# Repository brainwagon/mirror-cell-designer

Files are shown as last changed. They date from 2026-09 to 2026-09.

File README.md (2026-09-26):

# Mirror Cell Designer

A browser app that designs 3D-printable push-pull mirror cells for Newtonian telescopes. It exports **STEP** and **3MF**.

- **Live app:** https://mvandewettering.com/mirror-cell-designer/ (hosted on GitHub Pages).
- **App:** [`mirror-cell-designer.html`](mirror-cell-designer.html). It is a single self-contained file. Open it straight from disk (`file://`). There is no build step. The first load needs an internet connection, because the CAD kernel (~23 MB), three.js and fflate come from jsDelivr. After that the browser caches them.
- **Examples:** [`examples/`](examples). A 6" mirror in an 8" ID tube, and an 8" mirror in a 10" ID tube.
- **Tools (optional):** [`tools/build-examples.mjs`](tools/build-examples.mjs) regenerates the examples and runs a regression sweep. It extracts its geometry code from the HTML file, so the examples always match the app.

## Using the app

1. Pick the **mirror diameter**: 4.25", 6", 8" or 10". Each preset fills in a typical mirror thickness, tube ID and fan. All of these can be edited.
2. Enter the **mirror thickness** and the **tube inside diameter**. The in/mm toggle only changes how these inputs display. Internally everything is in mm.
3. Choose **retention**: RTV glue or clips.
4. Choose a **cooling fan**, or none. Fans too large for the mirror are greyed out.
5. Set your **printer bed** size. The default is 235 mm (e.g. an Anycubic Kobra S1); enter 220 for the brief's standard bed.
   Choose the **rear plate** style: *Ring* (default) or *3 spokes*, which prints smaller.
6. Check the tabs:
   - **3D preview:** the assembly with the mirror ghosted. There are toggles for hardware, the tube and a half-section, an explode slider, and a *Print layout* view. That view shows each part in its print orientation on a bed square, and the square turns red if the part doesn't fit.
   - **2D layout:** a dimensioned sheet with a rear view of the rear plate, a front view of the mirror plate, a section through a push-pull pair, and the clip. Hole letters (A–K) refer to the hole schedule.
   - **Checks:** every wall-thickness, thread-engagement, bolt-travel and clearance check, the CAD interference matrix, and the bed fit.
   - **Dimensions & BOM:** key dimensions, the hole schedule (sizes, depths, radii, angles, install direction) and the complete bill of materials (see below).
   - **Design decisions:** the choices listed below.
7. **Export:** a 3MF with all parts ready to print, a STEP of the assembly (parts in place, named and coloured), per-part 3MF/STEP in print orientation, the **bill of materials as CSV**, the drawing as SVG, and a Markdown report.

The design regenerates about 0.25 s after each change. Settings are kept in the URL hash, so a link reproduces a design. They are also kept in `localStorage`.

## How the cell works

```
 tube end (z=0)                                      toward the sky (+z)
   │ skirt │ rear plate │  gap  │ mirror plate │ pads │  mirror  │ clip
   ┃       ┃████████████┃       ┃██████████████┃  ▐▌  ┃▒▒▒▒▒▒▒▒▒▒┃
   ┃       ┃   push ▶───────────┫ (bears)      ┃  ▐▌  ┃          ┃
   ┃       ┃ pull ◀═════════════════(insert in pad column)       ┃
```

- The **rear tube plate** is a slip fit inside the tube: its diameter is the tube ID minus a 0.6 mm diametral clearance. A skirt runs rearward and sits flush with the tube end. Screws go through the tube wall into radial heat-set inserts in the skirt: 3 screws for tubes under 200 mm ID, 6 above. They are the same size as the push-pull bolts, so the push-pull and tube attachment share one insert size. Three vent windows keep the plate open for airflow.
- The **mirror plate** is a round core with three tapered arms. The arms carry the lateral posts. The mirror sits on three **pad columns** on a circle of **0.65 × mirror diameter**, which is close to the optimum for 3-point support.
- There are **three push-pull pairs** at 120°. Each **pull bolt** passes through a clearance hole in the rear plate and threads into a heat-set insert at the bottom of a pad column. Each **push bolt** threads through a heat-set insert in a boss on the rear plate and bears on the back of the mirror plate. A jam nut locks it. Both heads are reachable from behind the tube.
- **Bolts:** #10-24 for 4.25" and 6" mirrors, 1/4-20 for 8" and 10". Default travel at each pair is ±1 mm for 4.25", ±1.5 mm for 6", ±2 mm for 8" and ±2.5 mm for 10". This is sized so the worst case (one pair fully out, two fully in) tilts the mirror about 2.5°, several times what collimation needs. You can change it under *Advanced*. If you choose more travel, the pull-bolt clearance holes are enlarged automatically so the bolts don't bind as they tilt. The **plate gap is chosen to fit the bolts**: the pull bolt is the shortest standard length that fully engages its insert at maximum gap, and the gap is then set so it never bottoms out at minimum gap. The BOM lists every bolt length.
- **RTV:** each pad has a 2 mm-deep cup that sets the silicone thickness, and three lateral stops sit 0.75 mm from the mirror edge. **Clips:** the pads are flat. Three posts carry 3 mm clips that overlap the mirror face by 3 mm and sit 0.8 mm above it, so they never pinch the glass.
- **Fan (optional):** mounted on the back of the rear plate and blowing into the tube. Air goes through the plate's central opening and a matching hole in the mirror plate. It is held by thread-forming screws for plastics (#4 for 40 mm fans, #6 for larger ones) driven from the back into printed pilot holes, so there are no inserts or nuts to reach after assembly. The app assumes 4010, 6015, 8025, 9225 and 12025 frames.

## Strength

Plate thicknesses, lateral-post depth, arm ribs and RTV pad size are **sized from hand calculations**, not fixed. Each calculation appears as a row in the *Strength* table on the Checks tab and in `REPORT.md`, with its value, allowable, percentage used and formula.

| Load case | Checks |
|---|---|
| **Tube horizontal:** the whole mirror weight × 2 bears sideways on one post, at the mirror's mid-thickness | Post-root bending **across the layers** (posts print upright); arm bending at the post (T-section with an optional rib); RTV shear; pull-bolt bending across the plate gap |
| **Tube vertical:** locked preload plus each pair's share of the mirror-side weight × 2 | Pull- and push-insert pull-out; push-bolt tip and washer bearing; local plate bending where the pull and push bolts of a pair load the plate in opposite directions (mirror plate and rear plate); rear-plate spokes carrying the load out to the skirt; tube-screw bearing in the skirt |
| **Tube pointing down:** mirror weight × 2 on the clips or RTV | Clip bending and clip-screw insert pull-out, or RTV tension |

**What gets sized:**

| Part | Rule |
|---|---|
| Rear plate | max(rule of thumb, preload bending, spoke bending) |
| Mirror plate | max(rule of thumb, preload bending); thickened further only if an arm rib, capped 2 mm below the mirror, can't carry the lateral load |
| Lateral posts | deep enough for bending across the layers |
| RTV pads | large enough in area for the RTV to carry the load in shear |

The 8" example is typical: rear plate 8 mm (rule), mirror plate 7 mm (preload), a 6 × 4 mm arm rib, and 11 mm posts. At a 100 N lock preload, insert pull-out is about 24% of its allowable.

**Assumptions** are in the `STRENGTH` table at the top of the core in the HTML; edit them if you have better data.

| Assumption | Value |
|---|---|
| Glass density | 2.5 g/cm³ (plate glass; borosilicate is lighter, so this is conservative) |
| Handling factor on gravity loads | × 2 |
| Allowable along the layers | 10 MPa |
| Allowable across the layers | 5 MPa |
| Allowable bearing | 15 MPa |
| Allowable RTV shear/tension | 0.2 MPa |
| Section efficiency (walls, skins, 40% infill) | 0.8 |
| Heat-set insert pull-out, sustained | #4-40 150 N, #6-32 250 N, #8-32 300 N, #10-24 400 N, 1/4-20 500 N |
| Push-pull lock preload (Advanced setting) | 100 N per bolt ≈ 0.1–0.13 N·m, i.e. finger-snug; the BOM gives the torque for each bolt |

The plastic allowables are set at roughly 1/4–1/5 of typical short-term strengths for printed PETG and ASA, to cover creep, layer adhesion and print variability. The insert values are deliberately low; short-term tests of similar inserts usually fail well above them.

**Limits:** these are simple beam and plate formulas, not FEA. The pair-bending model (moment ≈ F·s/2 over a width ≈ s) is the crudest of them. They catch parts that are badly undersized, but they don't prove a safety margin. Stiffness is not checked, and neither is how far collimation drifts from creep; the low sustained allowables are the only guard against creep.

## Bill of materials

The BOM covers everything needed to build one cell. It appears on the *Dimensions & BOM* tab and in the report. It downloads as CSV from the **BOM .csv** button in the sidebar or the **Download CSV** button above the table. The rows are:

| Ref | Category | Contents |
|---|---|---|
| P1… | Printed part | Rear tube plate, mirror plate, clips. Each gives material, envelope, print settings and, once the solids are built, the bed footprint (flagged if oversize) and solid volume. |
| S1… | Screw | Pull and push bolts, tube screws, clip screws and fan screws, each with thread size and standard inch length. |
| N1… | Nut / washer | Push-bolt jam nuts (with across-flats size) and SAE washers under the pull-bolt heads. |
| I1… | Heat-set insert | Every insert, with length and the hole it expects. Identical inserts are merged; for example, #6-32 inserts used by both the clips and the fan become one line of 7. |
| F1 | Fan | Size, frame and hole spacing, when a fan is selected. |
| C1… | Consumable | Neutral-cure RTV (RTV mode only) and filament. |
| T1… | Tool | Hex keys and wrench sized for the specified hardware, the drill for the tube holes, and a soldering iron with insert tips. |

The CSV columns are `Ref, Category, Qty, Description, Size / spec, Length, Used in, Notes, Configuration`. The file is UTF-8 with a byte-order mark, so Excel and LibreOffice display Ø and inch marks correctly. The *Configuration* column repeats the design summary (mirror, tube, retention, fan, bolt size) on every row, so rows stay identifiable after you paste them into a larger parts list.

## Design decisions

These are the "decide and state" items from the brief. The app shows the same list on its *Design decisions* tab.

| Topic | Decision |
|---|---|
| **CAD kernel** | **replicad 1.1.0**: OpenCascade compiled to WebAssembly, loaded from jsDelivr. A true B-rep kernel is needed to write real STEP. JSCAD is mesh-only CSG and cannot export STEP. 3MF is written by a small built-in writer from the kernel's triangulation. Vertices are welded, so the meshes are watertight. The zip uses `fflate`. |
| **3MF print defaults** | **5 walls/perimeters, 40 % gyroid infill, 5 top and 5 bottom layers, 0.2 mm layers, supports off.** Five 0.4 mm walls make the ≥ 2 mm of material around every heat-set insert solid perimeter rather than infill. 40 % gyroid keeps the plates stiff. The values are written as per-object overrides that PrusaSlicer reads (`Metadata/Slic3r_PE_model.config`). OrcaSlicer/Bambu equivalents are also written (`Metadata/model_settings.config`), on a best-effort basis. The values are repeated in the model description so you can set them by hand in any slicer. Recommended material: **PETG or ASA**. PLA creeps under constant bolt load and softens in a hot car. |
| **Oversize parts** | Every part's footprint is measured at its best rotation about Z. If it exceeds the bed (default **235 × 235 mm**), a warning names the part, gives its size and states the bed size needed. **The part is still exported whole and full size. The app never splits or scales parts**, because a seam through a collimation plate costs stiffness and flatness. Your options are the 3-spoke rear plate, a larger bed, or cutting the part yourself with your slicer's *Cut* tool and dowel connectors. In practice, on a 235 mm bed: every part for 4.25", 6" and 8" mirrors fits, as long as an 8" mirror uses the 3-spoke rear plate in tubes over about 9.25" ID. For example, a 10" tube's ring plate is 253 mm but its 3-spoke plate is about 223 mm. An 8" mirror needs at least about 9.4" tube ID for post and tilt clearance, and the check reports the minimum. A 10" mirror's mirror plate is about 250 mm whatever the rear plate style, because its lateral posts must sit outside a 254 mm mirror. |
| **Rear plate style** | *Ring* (default): a full plate with a skirt around the tube wall, 3 or 6 tube screws and vent windows. *3 spokes* (option): a hub carrying the push-pull pairs and fan, with one 24 mm spoke per pair centred between its pull and push bolts, ending in a pad at the tube wall with one radial tube screw (3 in total, same size as the push-pull bolts). The spoke style is about 13% smaller across (the three tips at 120° fit a smaller square than a circle does) and uses about 40% less plastic. Three pads centre the plate in the tube and tolerate an out-of-round tube better than a ring. The spokes are covered by the same strength, wall and interference checks, with fillets where each spoke meets the hub (6 mm, in plane) and where it meets its tip pad (3 mm). |
| **Print orientation, no supports** | Rear plate: front face down, so the skirt and bosses grow upward. The radial tube-screw holes are **teardrops** pointing up. Mirror plate: rear face down, with pads and posts growing upward. Blind insert holes open onto the bed, and their small (< 8 mm) roofs bridge. Clips print flat. |
| **Fasteners** | Imperial only. Push-pull and tube screws share one size: #10-24 for 4.25"/6" mirrors, 1/4-20 for 8"/10". Clips use #6-32 inserts. The fan uses #4 or #6 thread-forming screws in printed pilot holes (no inserts). Inserts are tapered brass heat-set inserts for plastics. The dimensions are in the `FASTENERS` table at the top of the core in the HTML. Edit them there if your inserts differ. |
| **Fillets** | Inside corners are filleted to reduce stress concentration. **Rear plate:** 3 mm where the plate web meets the skirt, 1.5 mm at each push-boss root, 4 mm vent-window corners. **Mirror plate:** 2 mm where each pad column meets the plate, 3 mm along the inner face of each lateral post (the face in tension when the tube is horizontal; capped so it stays ≥ 2 mm below the mirror), 2 mm along both sides of each arm rib, and 8 mm in plane where each arm meets the core (tangent to the tapered arm edge and the core circle). All face up when printed or are vertical, so none need supports. The strength formulas assume these fillets remove the sharp-corner stress raisers; they add no factor for them. The fan is rotated automatically to the angle that best clears the push-pull hardware. |
| **Strength** | Thicknesses, lateral-post depth, arm ribs and RTV pad size are sized by hand calculations against sustained allowables for printed PETG/ASA (see *Strength*). Lock the push-pull pairs finger-snug: about 100 N per bolt, the torque listed in the BOM. |
| **Wall rules** | The generator aims for 3 mm around inserts, measured from the insert's **outside** diameter, not the hole. Every insert and through-hole must have **≥ 2 mm** to the nearest hole, cut-out or edge. Blind holes keep ≥ 2 mm of cap. Cut-outs keep ≥ 4 mm of web to bolt features. |

### Assumed hardware (edit `FASTENERS` in the HTML if yours differ)

| Size | Clearance hole | Insert hole | Insert OD | Insert length |
|---|---|---|---|---|
| #4-40 | 3.4 | 3.2 | 3.8 | 3.8 |
| #6-32 | 4.0 | 4.0 | 4.6 | 4.8 |
| #8-32 | 4.7 | 4.7 | 5.3 | 5.6 |
| #10-24 | 5.4 | 5.6 | 6.3 | 6.4 |
| 1/4-20 | 7.0 | 7.6 | 8.4 | 8.0 |

Clearance holes are a "normal fit" plus about 0.2 mm for printing. Insert sizes vary by brand, so check the hole diameter your inserts call for.

## Verification (definition of done)

- **All dimensions specified:** the 2D sheet, the hole schedule (diameter, depth, radius, angle, install face), the key-dimension table and the BOM (CSV) with bolt lengths are all generated from the same numbers as the solids. Each example has a `REPORT.md` with the full set.
- **Wall thickness:** analytic 2D checks cover every insert and through-hole against every other hole, cut-out, boss edge and plate edge. They also cover blind-hole caps, insert-fits-in-boss, skirt thickness, clip-hole walls and radial-insert edge distance. The 6" example has 41 checks and the 8" clip example has 49, and all pass.
- **No interference:** the app builds every body at its installed position: rear plate, mirror plate, clips, mirror, tube (with screw holes), fan, and every bolt, washer and jam nut. It then runs an OpenCascade boolean intersection on **every pair**. The mirror side (mirror plate, clips, mirror) is also moved into all **8 extreme collimation poses** (each pair at +travel or −travel) and intersected with the tube and the rear plate. The pose model pivots about the pull-bolt holes in the rear plate. The same 8 poses drive analytic checks: radial clearance to the tube (≥ 1 mm), axial gap to the rear plate and the fan-screw tips, pull-bolt tilt room in its clearance hole, and slide of the push-bolt contact point. Touching faces count as zero overlap. Heat-set inserts are left out on purpose, since they are meant to melt into their holes. Pull-bolt engagement and bottoming, push-bolt length and radial clearance to the tube at full tilt are checked analytically. A negative control (the mirror lowered 0.5 mm into the pads, a push bolt 1 mm too long) was confirmed to be caught.
- **Downloads:** the STEP and 3MF buttons produce files in the browser. This was tested in headless Chrome loading the page from `file://`. The exported STEP re-imports into OpenCascade with the exact expected volumes. OrcaSlicer's `--info` reports every 3MF object as manifold, with volumes matching the CAD.
- **Strength:** 13–14 hand-calculation checks per configuration, covering three load cases. All pass for every preset, because the sized dimensions are chosen to satisfy them.
- **Regression sweep:** `node tools/build-examples.mjs --sweep` builds every preset × retention × fan combination and runs all checks plus the CAD interference test. Every buildable combination passes. Fans too big for a given mirror are rejected with a clear message: for example, anything over 40 mm on a 4.25" mirror, or over 60 mm on a 6".

## Regenerating the examples

```sh
cd tools
npm install
node build-examples.mjs                   # rewrites ../examples/*
node build-examples.mjs --sweep           # regression over all presets
node build-examples.mjs --mirror 8 --tube 9.25 --retention rtv --fan 60 --out ../my-cell
```

Each example folder contains:

| File | What it is |
|---|---|
| `*.3mf` | All printed parts, oriented and placed for printing, with the print settings embedded |
| `*-assembly.step` | Printed parts in their assembled positions (z = 0 at the tube end, +Z toward the sky) |
| `*-<part>-print.step` | Each part alone, in print orientation |
| `*-drawing.svg` | The dimensioned 2D layout |
| `*-bom.csv` | Complete bill of materials: printed parts, hardware, inserts, fan, consumables, tools |
| `REPORT.md` | Key dimensions, hole schedule, BOM, every check, interference matrix and bed fit |

| Example | Configuration | Bed fit (235 mm) |
|---|---|---|
| `6in-mirror-8in-tube` | 6" × 25.4 mm mirror, 8.000" ID, RTV, 60 mm fan, ring rear plate | all parts fit |
| `8in-mirror-10in-tube` | 8" × 32 mm mirror, 10.000" ID, clips, 80 mm fan, ring rear plate | **rear plate 253.4 mm — oversize** (needs ≥ 254 mm bed; see policy) |
| `8in-mirror-10in-tube-spokes` | same, with the 3-spoke rear plate | all parts fit (rear plate about 223 mm) |

## Assembly notes

1. Press the heat-set inserts in with the part cold and fully cured:
   - **Rear plate:** push-bolt inserts from the rear face and tube-screw inserts radially from outside the skirt.
   - **Mirror plate:** pull-bolt inserts from the rear face, and clip inserts from the tops of the posts.
2. **Wear pads:** on the mirror plate's rear face, cement a small steel flat washer over each of the three Ø1 mm marks (hole schedule M) using epoxy or CA. Use #6 SAE for #10-24 push bolts and #10 SAE for 1/4-20. The push-bolt tips then bear on steel, not plastic.
3. Fit the three push bolts with their jam nuts into the rear plate, backed out so they protrude only a little.
4. Put the pull bolts, with washers, through the rear plate and thread them into the mirror plate until the plates sit at roughly the nominal gap shown in the report.
5. **RTV:** put a blob of neutral-cure silicone in each pad cup. Lower the mirror onto the pad rims, which set the 2 mm layer. Leave it face-up for 24 h. **Clips:** place the mirror on the pads and screw the clips on. They should not touch the glass.
6. Slide the cell into the tube so the skirt is flush with the tube end. Drill through the tube at the skirt inserts (the angles and distance from the tube end are in the hole schedule) and fit the tube screws (same size as the push-pull bolts; drill size is in the BOM).
7. **Collimate:** loosen the push bolts, adjust with the pull bolts, then run the push bolts down and lock the jam nuts.

## Limitations

- Insert dimensions are generic. Confirm them against the inserts you buy.
- The OrcaSlicer/Bambu per-object settings in the 3MF are best effort. OrcaSlicer loads the files and reports them manifold, but I did not confirm that it applies the embedded wall and infill values. PrusaSlicer's per-object format is the primary one. Cura ignores both, so set the values by hand there.
- The app runs the CAD kernel on the main thread, so the page pauses for about 1–3 s while solids rebuild.

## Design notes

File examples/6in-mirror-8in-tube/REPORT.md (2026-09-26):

# Mirror cell: 6" mirror in 203.2 mm (8") ID tube

Retention: **RTV** · Fan: **60 mm** · Push-pull: **3 × #10-24 pairs** · Bed: 235 mm

## Key dimensions (mm)
| Group | Dimension | Value |
|---|---|---|
| Rear plate | Style | full ring (plate + skirt) |
| Rear plate | Outside diameter (tube ID − fit) | 202.6 mm (7.976") |
| Rear plate | Skirt inside diameter | 187 mm (7.362") |
| Rear plate | Overall height (skirt + plate) | 18 mm (0.709") |
| Rear plate | Plate thickness (sized) | 6.5 mm = max(rule 6, preload 6.5, spokes 2.5) |
| Rear plate | Push boss Ø × height | 12.3 × 10.4 mm |
| Push-pull | Bolt size | #10-24 |
| Push-pull | Pair circle diameter | 99.1 mm (3.9") |
| Push-pull | Pull-to-push spacing (chord) | 14.5 mm (16.83°) |
| Push-pull | Nominal plate gap | 16.15 mm (±1.5 mm travel) |
| Push-pull | Max tilt at full travel (one pair out, two in) | 2.31° |
| Mirror plate | Inside fillets: pad roots / post inner faces / rib sides / arm roots (in plane) | 2 / 3 / — / 8 mm |
| Rear plate | Inside fillets: skirt joint / boss roots / window corners | 3 / 1.5 / 4 mm |
| Mirror plate | Core diameter | 121.5 mm (4.782") |
| Mirror plate | Span across posts | 169.9 mm (6.689") |
| Mirror plate | Base thickness (sized) | 6.5 mm — governed by push-pull preload (rule 5, preload 6.5) |
| Mirror plate | Arm rib (width × height) | none needed |
| Mirror plate | Lateral post depth (sized) | 8 mm (minimum 8) |
| Loads | Mirror mass (glass at 2.5 g/cm³) | 1.16 kg |
| Loads | Push-pull lock preload / torque | 100 N per bolt ≈ 0.1 N·m (finger-snug) |
| Mirror plate | Pad Ø × height above base | 12.4 × 8.9 mm |
| Mirror plate | Post top above mirror-plate rear face | 28.1 mm |
| Mirror | Diameter / thickness | 152.4 / 25.4 mm |
| Mirror | Mirror face above tube end | 74.9 mm (2.951") |
| Assembly | Overall cell height | 74.9 mm (2.951") |

## Hole schedule
| Part | Label | Qty | Feature | Size | Location | Install |
|---|---|---|---|---|---|---|
| Rear plate | A | 3 | #10-24 heat-set insert (push bolt) | Ø5.6 thru boss (10.4 tall) | R49.53 @ 106.8°, 226.8°, 346.8° | from rear face |
| Rear plate | B | 3 | #10-24 clearance (pull bolt) | Ø5.4 thru | R49.53 @ 90°, 210°, 330° |  |
| Rear plate | C | 6 | #10-24 heat-set insert (tube screw), radial teardrop | Ø5.6 thru skirt (7.8) | 30°, 90°, 150°, 210°, 270°, 330°; 5.75 from tube end | from outside of skirt |
| Rear plate | D | 4 | #6 thread-forming screw pilot (fan) | Ø2.8 thru | 50 × 50 square, rotated 22° | screw in from rear face |
| Rear plate | E | 1 | Fan opening | Ø57 thru | centre |  |
| Rear plate | F | 3 | Vent window (annular sector) | R45.4–R89.5, 77.5° wide | 120.4°–197.9°, 240.4°–317.9°, 0.4°–77.9° |  |
| Mirror plate | G | 3 | #10-24 heat-set insert (pull bolt), blind | Ø5.6 × 10.9 deep | R49.53 @ 90°, 210°, 330° | from rear face (bed side) |
| Mirror plate | H | 3 | RTV cup in pad top | Ø9.4 × 2 deep | R49.53 @ 90°, 210°, 330° |  |
| Mirror plate | M | 3 | Wear-washer locating mark (push-bolt contact) | Ø1 × 1 deep | R49.53 @ 106.8°, 226.8°, 346.8° | rear face (bed side) |
| Mirror plate | I | 1 | Central vent | Ø57 thru | centre |  |
| Mirror plate | J | 3 | Vent hole | Ø24 thru | R44.61 @ 158.4°, 278.4°, 38.4° |  |

## Bill of materials (per cell)
| Ref | Category | Qty | Description | Size / spec | Length | Used in | Notes |
|---|---|---|---|---|---|---|---|
| P1 | Printed part | 1 | Rear tube plate | PETG or ASA; Ø202.6 × 18 mm |  | tube end | 5 walls, 40% gyroid, 0.2 mm layers, no supports; footprint 202.5 × 202.5 mm; solid volume 169.6 cm³ |
| P2 | Printed part | 1 | Mirror plate | PETG or ASA; 169.9 mm across posts × 28.1 mm tall |  | carries the mirror | 5 walls, 40% gyroid, 0.2 mm layers, no supports; footprint 148.9 × 148.9 mm; solid volume 67.1 cm³ |
| S1 | Screw | 3 | Socket head cap screw (pull / adjust) | #10-24 | 1-1/4" | rear plate → mirror plate pad inserts | a thumbscrew or knob of the same length also works; lock at ≈ 0.1 N·m |
| S2 | Screw | 3 | Socket head cap screw (push / lock) | #10-24 | 1-1/2" | rear-plate push bosses | fully threaded; lock at ≈ 0.1 N·m |
| S3 | Screw | 6 | Button head socket cap screw (tube attachment) | #10-24 | 1/2" | through tube wall into skirt | sized for a 3.18 mm tube wall |
| S4 | Screw | 4 | Thread-forming screw for plastics, pan head (fan mount) | #6 | 7/8" | fan → rear plate pilot holes | e.g. Hi-Lo or 48° plastic-forming thread; Ø2.8 mm pilot holes; don't overtighten |
| N1 | Nut / washer | 3 | Hex jam nut | #10-24 |  | push bolts | 3/8" across flats |
| N2 | Nut / washer | 3 | Flat washer, SAE | #10-24 |  | under pull-bolt heads | Ø12.7 mm OD |
| N3 | Nut / washer | 3 | Steel flat washer (wear pad for the push-bolt tip) | #6 SAE (≈ Ø9.5 OD, Ø4 hole, 1.2 thick) |  | cemented to the mirror plate rear face at the Ø1 marks | hole must be smaller than the Ø4.8 bolt tip; epoxy or CA |
| I1 | Heat-set insert | 12 | Brass heat-set insert (tapered, for plastics) | #10-24, 6.4 mm long, for Ø5.6 mm hole |  | rear plate, push bosses; mirror plate, pad columns; rear-plate skirt (radial) | install from rear face; install from outside |
| F1 | Fan | 1 | 60 mm 12 V DC fan | 6015 (60 × 60 × 15 mm), 50 mm hole spacing |  | rear face of rear plate | blows into the tube; 12 V supply and lead not included |
| C1 | Consumable | 1 | Neutral-cure silicone RTV | alkoxy/oxime cure — not acetic (vinegar-smelling) |  | pad cups | 3 blobs, 2 mm thick |
| C2 | Consumable | 1 | Filament | PETG or ASA |  | all printed parts | PLA not recommended (creeps under bolt load) |
| T1 | Tool | 1 | Hex key | 5/32" |  | #10-24 socket heads |  |
| T2 | Tool | 1 | Hex key | 1/8" |  | #10-24 button heads |  |
| T3 | Tool | 1 | Wrench | 3/8" |  | push-bolt jam nuts |  |
| T4 | Tool | 1 | Screwdriver | Phillips #2 |  | #6 fan screws |  |
| T5 | Tool | 1 | Drill bit | 13/64" (5.2 mm) |  | 6 tube-wall holes for #10-24 | positions are in the hole schedule (C) |
| T6 | Tool | 1 | Soldering iron with heat-set insert tips | #10-24 |  | installing inserts | or a dedicated insert press |

## Checks
| Part | Check | Value (mm) | Required | Result |
|---|---|---|---|---|
| Rear plate | wall around pull clearance hole P1 | 7.63 | ≥ 2 | PASS |
| Rear plate | wall around push insert P1 | 3 | ≥ 2 | PASS |
| Rear plate | wall around pull clearance hole P2 | 7.63 | ≥ 2 | PASS |
| Rear plate | wall around push insert P2 | 3 | ≥ 2 | PASS |
| Rear plate | wall around pull clearance hole P3 | 7.63 | ≥ 2 | PASS |
| Rear plate | wall around push insert P3 | 3 | ≥ 2 | PASS |
| Rear plate | wall around fan screw pilot F1 | 5.1 | ≥ 2 | PASS |
| Rear plate | wall around fan screw pilot F2 | 5.1 | ≥ 2 | PASS |
| Rear plate | wall around fan screw pilot F3 | 5.1 | ≥ 2 | PASS |
| Rear plate | wall around fan screw pilot F4 | 5.1 | ≥ 2 | PASS |
| Rear plate | solid bearing under pull washer P1 | 3.98 | ≥ 0.5 | PASS |
| Rear plate | push boss P1 (incl. root fillet) clear of cut-outs | 3.98 | ≥ 0.5 | PASS |
| Rear plate | solid bearing under pull washer P2 | 3.98 | ≥ 0.5 | PASS |
| Rear plate | push boss P2 (incl. root fillet) clear of cut-outs | 3.98 | ≥ 0.5 | PASS |
| Rear plate | solid bearing under pull washer P3 | 3.98 | ≥ 0.5 | PASS |
| Rear plate | push boss P3 (incl. root fillet) clear of cut-outs | 3.98 | ≥ 0.5 | PASS |
| Rear plate | wall: tube-screw insert to skirt edge | 2.6 | ≥ 2 | PASS |
| Rear plate | skirt thickness ≥ tube insert length | 1.4 | ≥ 0 | PASS |
| Rear plate | push insert fits boss height | 4 | ≥ 0 | PASS |
| Rear plate | wall between tube-screw inserts | 95 | ≥ 2 | PASS |
| Mirror plate | wall around pull insert P1 | 3.05 | ≥ 2 | PASS |
| Mirror plate | wall around pull insert P2 | 3.05 | ≥ 2 | PASS |
| Mirror plate | wall around pull insert P3 | 3.05 | ≥ 2 | PASS |
| Mirror plate | wear-washer seat P1 on solid plastic (Ø9.5, incl. 0.8 mm slide at full tilt) | 5.67 | ≥ 0.5 | PASS |
| Mirror plate | push-bolt tip (Ø4.83) larger than the wear-washer hole (Ø4) | 0.83 | ≥ 0.3 | PASS |
| Mirror plate | pad column P1 (incl. root fillet) clear of vents | 12.83 | ≥ 1 | PASS |
| Mirror plate | wear-washer seat P2 on solid plastic (Ø9.5, incl. 0.8 mm slide at full tilt) | 5.67 | ≥ 0.5 | PASS |
| Mirror plate | pad column P2 (incl. root fillet) clear of vents | 12.83 | ≥ 1 | PASS |
| Mirror plate | wear-washer seat P3 on solid plastic (Ø9.5, incl. 0.8 mm slide at full tilt) | 5.67 | ≥ 0.5 | PASS |
| Mirror plate | pad column P3 (incl. root fillet) clear of vents | 12.83 | ≥ 1 | PASS |
| Mirror plate | arm-root fillet (R8) ends inboard of the lateral post | 10.79 | ≥ 0 | PASS |
| Mirror plate | cap above pull insert hole | 2.5 | ≥ 2 | PASS |
| Push-pull | pull-bolt engagement at max gap (17.7 mm) | 6.4 | ≥ 6.4 | PASS |
| Push-pull | pull-bolt tip depth at min gap (14.7 mm) | 9.4 | ≤ 10.4 | PASS |
| Push-pull | push-bolt length left for jam nut at max gap | 10.05 | ≥ 4.2 | PASS |
| Push-pull | min plate gap at full travel | 14.65 | ≥ 5 | PASS |
| Push-pull | pair spacing (pull washer to push-boss root fillet) | 0.5 | ≥ 0.5 | PASS |
| Fan | fan-screw tip protrusion past plate front (must clear mirror plate) | 0.72 | ≤ 13.65 | PASS |
| Fan | fan-screw thread engagement in the plate (#6 thread-forming) | 6.5 | ≥ 5.27 | PASS |
| Assembly | radial clearance to tube, worst of 8 poses at ±1.5 mm per pair (2.3° max tilt, pose −++); needs tube ID ≥ 177.2 mm (6.98") | 14.01 | ≥ 1 | PASS |
| Assembly | axial gap mirror plate ↔ rear plate, worst pose (+−−) | 12.8 | ≥ 1 | PASS |
| Assembly | gap mirror plate ↔ fan-screw tips, worst pose | 13.51 | ≥ 0.5 | PASS |
| Push-pull | pull-bolt tilt room in rear-plate hole at 2.3° | 0.31 | ≥ 0.1 | PASS |
| Assembly | mirror edge to lateral post gap | 0.75 | ≥ 0.25 | PASS |
| Assembly | rear plate radial fit clearance | 0.3 | ≥ 0.1 | PASS |

## Strength (hand calculations, sustained allowables for printed PETG/ASA)
| Load case | Item | Value | Allowable | Utilisation | Result |
|---|---|---|---|---|---|
| Tube horizontal: 22.7 N lateral (mirror 1.16 kg × 2) | lateral post root bending, across layers (8 × 14 mm post, load 21.6 mm up) | 4.11 MPa | 5 MPa | 82% | PASS |
| Tube horizontal: 22.7 N lateral (mirror 1.16 kg × 2) | arm bending at the post (15.2 × 6.5 mm arm) | 6.6 MPa | 10 MPa | 66% | PASS |
| Tube horizontal: 22.7 N lateral (mirror 1.16 kg × 2) | RTV shear, 3 pads Ø9.4 mm | 0.11 MPa | 0.2 MPa | 55% | PASS |
| Tube horizontal: 22.7 N lateral (mirror 1.16 kg × 2) | pull-bolt bending across the gap (steel, #10-24 root Ø3.5) | 34.91 MPa | 250 MPa | 14% | PASS |
| Tube vertical: preload 100 N + 8.4 N weight share per pair | pull-bolt insert pull-out (mirror plate, #10-24) | 108.36 N | 400 N | 27% | PASS |
| Tube vertical: preload 100 N + 8.4 N weight share per pair | push-bolt insert pull-out (rear plate, #10-24) | 108.36 N | 400 N | 27% | PASS |
| Tube vertical: preload 100 N + 8.4 N weight share per pair | push-bolt load on mirror plate through the Ø9.5 wear washer | 1.86 MPa | 15 MPa | 12% | PASS |
| Tube vertical: preload 100 N + 8.4 N weight share per pair | pull-bolt washer bearing on rear plate | 1.04 MPa | 15 MPa | 7% | PASS |
| Tube vertical: preload 100 N + 8.4 N weight share per pair | mirror plate local bending at each pair (t = 6.5 mm) | 9.62 MPa | 10 MPa | 96% | PASS |
| Tube vertical: preload 100 N + 8.4 N weight share per pair | rear plate local bending at each pair (t = 6.5 mm) | 9.62 MPa | 10 MPa | 96% | PASS |
| Tube vertical: preload 100 N + 8.4 N weight share per pair | rear plate spokes carrying the mirror side to the skirt (66 mm wide) | 0.98 MPa | 10 MPa | 10% | PASS |
| Tube vertical: preload 100 N + 8.4 N weight share per pair | tube-screw bearing in the skirt (6 × #10-24, cell 1.82 kg) | 0.16 MPa | 15 MPa | 1% | PASS |
| Tube pointing down: 7.6 N on each RTV pad | RTV tension | 0.11 MPa | 0.2 MPa | 55% | PASS |

## Interference (CAD boolean intersection of every pair of bodies)
| Body A | Body B | Overlap volume (mm³) | Result |
|---|---|---|---|
| Rear tube plate | Mirror plate | 0 | PASS |
| Rear tube plate | Mirror | 0 | PASS |
| Rear tube plate | Tube | 0 | PASS |
| Rear tube plate | Fan | 0 | PASS |
| Rear tube plate | Bolts, nuts & washers | 0 | PASS |
| Mirror plate | Mirror | 0 | PASS |
| Mirror plate | Tube | 0 | PASS |
| Mirror plate | Fan | 0 | PASS |
| Mirror plate | Bolts, nuts & washers | 0 | PASS |
| Mirror | Tube | 0 | PASS |
| Mirror | Fan | 0 | PASS |
| Mirror | Bolts, nuts & washers | 0 | PASS |
| Tube | Fan | 0 | PASS |
| Tube | Bolts, nuts & washers | 0 | PASS |
| Fan | Bolts, nuts & washers | 0 | PASS |
| Mirror side tilted (worst of 8 poses, 2.3° max) | Tube | 0 | PASS |
| Mirror side tilted (worst of 8 poses, 2.3° max) | Rear tube plate | 0 | PASS |

## Print bed fit (235 × 235 mm)
| Part | Footprint (mm) | Height (mm) | Fits |
|---|---|---|---|
| Rear tube plate | 202.5 × 202.5 | 18 | yes |
| Mirror plate | 148.9 × 148.9 | 28.1 | yes |

## Print settings (embedded in the 3MF)
5 walls/perimeters, 40% gyroid infill, 5 top and 5 bottom layers, 0.2 mm layers, no supports. Material: PETG or ASA (avoid PLA: it creeps under the constant bolt load and softens in a hot car).

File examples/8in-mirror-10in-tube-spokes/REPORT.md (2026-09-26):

# Mirror cell: 8" mirror in 254 mm (10") ID tube

Retention: **clips** · Fan: **80 mm** · Push-pull: **3 × 1/4-20 pairs** · Bed: 235 mm

## Key dimensions (mm)
| Group | Dimension | Value |
|---|---|---|
| Rear plate | Style | 3 spokes (hub + spokes, 3 tube screws) |
| Rear plate | Spoke-tip circle diameter (tube ID − fit) | 253.4 mm (9.976") |
| Rear plate | Hub diameter | 158 mm (6.22") |
| Rear plate | Spoke / tip-pad width | 24 mm, spokes at 97.6°, 217.6°, 337.6° |
| Rear plate | Overall height (skirt + plate) | 21.5 mm (0.846") |
| Rear plate | Plate thickness (sized) | 8 mm = max(rule 8, preload 7, spokes 6.5) |
| Rear plate | Push boss Ø × height | 14.4 × 12 mm |
| Push-pull | Bolt size | 1/4-20 |
| Push-pull | Pair circle diameter | 132.1 mm (5.2") |
| Push-pull | Pull-to-push spacing (chord) | 17.5 mm (15.23°) |
| Push-pull | Nominal plate gap | 12.05 mm (±2 mm travel) |
| Push-pull | Max tilt at full travel (one pair out, two in) | 2.31° |
| Mirror plate | Inside fillets: pad roots / post inner faces / rib sides / arm roots (in plane) | 2 / 3 / 2 / 8 mm |
| Rear plate | Inside fillets: tip-pad joint / boss roots / spoke roots (in plane) | 3 / 1.5 / 6 mm |
| Mirror plate | Core diameter | 156.5 mm (6.161") |
| Mirror plate | Span across posts | 226.7 mm (8.925") |
| Mirror plate | Base thickness (sized) | 7 mm — governed by push-pull preload (rule 6, preload 7) |
| Mirror plate | Arm rib (width × height) | 6 × 4 mm |
| Mirror plate | Lateral post depth (sized) | 11 mm (minimum 11) |
| Loads | Mirror mass (glass at 2.5 g/cm³) | 2.59 kg |
| Loads | Push-pull lock preload / torque | 100 N per bolt ≈ 0.13 N·m (finger-snug) |
| Mirror plate | Pad Ø × height above base | 14.4 × 9 mm |
| Mirror plate | Post top above mirror-plate rear face | 48.8 mm |
| Mirror | Diameter / thickness | 203.2 / 32 mm |
| Mirror | Mirror face above tube end | 81.6 mm (3.211") |
| Assembly | Overall cell height | 85.4 mm (3.36") |

## Hole schedule
| Part | Label | Qty | Feature | Size | Location | Install |
|---|---|---|---|---|---|---|
| Rear plate | A | 3 | 1/4-20 heat-set insert (push bolt) | Ø7.6 thru boss (12 tall) | R66.04 @ 105.2°, 225.2°, 345.2° | from rear face |
| Rear plate | B | 3 | 1/4-20 clearance (pull bolt) | Ø7 thru | R66.04 @ 90°, 210°, 330° |  |
| Rear plate | C | 3 | 1/4-20 heat-set insert (tube screw), radial teardrop | Ø7.6 thru tip pad (9.4) | 97.6°, 217.6°, 337.6°; 6.75 from tube end | from outside of skirt |
| Rear plate | D | 4 | #6 thread-forming screw pilot (fan) | Ø2.8 thru | 71.5 × 71.5 square, rotated 22° | screw in from rear face |
| Rear plate | E | 1 | Fan opening | Ø76 thru | centre |  |
| Mirror plate | G | 3 | 1/4-20 heat-set insert (pull bolt), blind | Ø7.6 × 13.5 deep | R66.04 @ 90°, 210°, 330° | from rear face (bed side) |
| Mirror plate | H | 3 | #6-32 heat-set insert (clip), blind | Ø4 × 7.3 deep | R107.85 @ 90°, 210°, 330° | from top of post |
| Mirror plate | M | 3 | Wear-washer locating mark (push-bolt contact) | Ø1 × 1 deep | R66.04 @ 105.2°, 225.2°, 345.2° | rear face (bed side) |
| Mirror plate | I | 1 | Central vent | Ø76 thru | centre |  |
| Mirror plate | J | 3 | Vent hole | Ø32 thru | R58.12 @ 157.6°, 277.6°, 37.6° |  |
| Clip | K | 3 | #6-32 clearance | Ø4 thru | 9.25 from inner end |  |

## Bill of materials (per cell)
| Ref | Category | Qty | Description | Size / spec | Length | Used in | Notes |
|---|---|---|---|---|---|---|---|
| P1 | Printed part | 1 | Rear tube plate | PETG or ASA; Ø253.4 × 21.5 mm |  | tube end | 5 walls, 40% gyroid, 0.2 mm layers, no supports; footprint 223 × 222.2 mm; solid volume 155.4 cm³ |
| P2 | Printed part | 1 | Mirror plate | PETG or ASA; 226.7 mm across posts × 48.8 mm tall |  | carries the mirror | 5 walls, 40% gyroid, 0.2 mm layers, no supports; footprint 197.4 × 197.4 mm; solid volume 127.7 cm³ |
| P3 | Printed part | 3 | Mirror clip | PETG or ASA; 14.8 × 16 × 3 mm |  | clip posts | 5 walls, 40% gyroid, 0.2 mm layers, no supports; footprint 14.8 × 16 mm; solid volume 0.7 cm³ |
| S1 | Screw | 3 | Socket head cap screw (pull / adjust) | 1/4-20 | 1-1/4" | rear plate → mirror plate pad inserts | a thumbscrew or knob of the same length also works; lock at ≈ 0.13 N·m |
| S2 | Screw | 3 | Socket head cap screw (push / lock) | 1/4-20 | 1-1/4" | rear-plate push bosses | fully threaded; lock at ≈ 0.13 N·m |
| S3 | Screw | 3 | Button head socket cap screw (tube attachment) | 1/4-20 | 1/2" | through tube wall into skirt | sized for a 3.18 mm tube wall |
| S4 | Screw | 3 | Socket head cap screw (clips) | #6-32 | 3/8" | clips → clip posts |  |
| S5 | Screw | 4 | Thread-forming screw for plastics, pan head (fan mount) | #6 | 1-1/2" | fan → rear plate pilot holes | e.g. Hi-Lo or 48° plastic-forming thread; Ø2.8 mm pilot holes; don't overtighten |
| N1 | Nut / washer | 3 | Hex jam nut | 1/4-20 |  | push bolts | 7/16" across flats |
| N2 | Nut / washer | 3 | Flat washer, SAE | 1/4-20 |  | under pull-bolt heads | Ø15.9 mm OD |
| N3 | Nut / washer | 3 | Steel flat washer (wear pad for the push-bolt tip) | #10 SAE (≈ Ø12.7 OD, Ø5.6 hole, 1.2 thick) |  | cemented to the mirror plate rear face at the Ø1 marks | hole must be smaller than the Ø6.4 bolt tip; epoxy or CA |
| I1 | Heat-set insert | 9 | Brass heat-set insert (tapered, for plastics) | 1/4-20, 8 mm long, for Ø7.6 mm hole |  | rear plate, push bosses; mirror plate, pad columns; rear-plate spoke tips (radial) | install from rear face; install from outside |
| I2 | Heat-set insert | 3 | Brass heat-set insert (tapered, for plastics) | #6-32, 4.8 mm long, for Ø4 mm hole |  | clip posts | install from top of post |
| F1 | Fan | 1 | 80 mm 12 V DC fan | 8025 (80 × 80 × 25 mm), 71.5 mm hole spacing |  | rear face of rear plate | blows into the tube; 12 V supply and lead not included |
| C1 | Consumable | 1 | Filament | PETG or ASA |  | all printed parts | PLA not recommended (creeps under bolt load) |
| T1 | Tool | 1 | Hex key | 3/16" |  | 1/4-20 socket heads |  |
| T2 | Tool | 1 | Hex key | 5/32" |  | 1/4-20 button heads |  |
| T3 | Tool | 1 | Hex key | 7/64" |  | #6-32 clip screws |  |
| T4 | Tool | 1 | Wrench | 7/16" |  | push-bolt jam nuts |  |
| T5 | Tool | 1 | Screwdriver | Phillips #2 |  | #6 fan screws |  |
| T6 | Tool | 1 | Drill bit | 17/64" (6.7 mm) |  | 3 tube-wall holes for 1/4-20 | positions are in the hole schedule (C) |
| T7 | Tool | 1 | Soldering iron with heat-set insert tips | 1/4-20, #6-32 |  | installing inserts | or a dedicated insert press |

## Checks
| Part | Check | Value (mm) | Required | Result |
|---|---|---|---|---|
| Rear plate | wall around pull clearance hole P1 | 9.46 | ≥ 2 | PASS |
| Rear plate | wall around push insert P1 | 3 | ≥ 2 | PASS |
| Rear plate | wall around pull clearance hole P2 | 9.46 | ≥ 2 | PASS |
| Rear plate | wall around push insert P2 | 3 | ≥ 2 | PASS |
| Rear plate | wall around pull clearance hole P3 | 9.46 | ≥ 2 | PASS |
| Rear plate | wall around push insert P3 | 3 | ≥ 2 | PASS |
| Rear plate | wall around fan screw pilot F1 | 10.8 | ≥ 2 | PASS |
| Rear plate | wall around fan screw pilot F2 | 10.8 | ≥ 2 | PASS |
| Rear plate | wall around fan screw pilot F3 | 10.8 | ≥ 2 | PASS |
| Rear plate | wall around fan screw pilot F4 | 10.8 | ≥ 2 | PASS |
| Rear plate | solid bearing under pull washer P1 | 5.01 | ≥ 0.5 | PASS |
| Rear plate | push boss P1 (incl. root fillet) clear of cut-outs | 4.26 | ≥ 0.5 | PASS |
| Rear plate | solid bearing under pull washer P2 | 5.01 | ≥ 0.5 | PASS |
| Rear plate | push boss P2 (incl. root fillet) clear of cut-outs | 4.26 | ≥ 0.5 | PASS |
| Rear plate | solid bearing under pull washer P3 | 5.01 | ≥ 0.5 | PASS |
| Rear plate | push boss P3 (incl. root fillet) clear of cut-outs | 4.26 | ≥ 0.5 | PASS |
| Rear plate | wall: tube-screw insert to tip pad edge | 2.55 | ≥ 2 | PASS |
| Rear plate | wall: tube-screw insert to sides of spoke tip pad | 7.8 | ≥ 2 | PASS |
| Rear plate | skirt thickness ≥ tube insert length | 1.4 | ≥ 0 | PASS |
| Rear plate | push insert fits boss height | 4 | ≥ 0 | PASS |
| Rear plate | wall between tube-screw inserts | 211.05 | ≥ 2 | PASS |
| Mirror plate | wall around pull insert P1 | 3 | ≥ 2 | PASS |
| Mirror plate | wall around pull insert P2 | 3 | ≥ 2 | PASS |
| Mirror plate | wall around pull insert P3 | 3 | ≥ 2 | PASS |
| Mirror plate | wear-washer seat P1 on solid plastic (Ø12.7, incl. 0.6 mm slide at full tilt) | 5.2 | ≥ 0.5 | PASS |
| Mirror plate | push-bolt tip (Ø6.35) larger than the wear-washer hole (Ø5.6) | 0.75 | ≥ 0.3 | PASS |
| Mirror plate | pad column P1 (incl. root fillet) clear of vents | 18.84 | ≥ 1 | PASS |
| Mirror plate | wear-washer seat P2 on solid plastic (Ø12.7, incl. 0.6 mm slide at full tilt) | 5.2 | ≥ 0.5 | PASS |
| Mirror plate | pad column P2 (incl. root fillet) clear of vents | 18.84 | ≥ 1 | PASS |
| Mirror plate | wear-washer seat P3 on solid plastic (Ø12.7, incl. 0.6 mm slide at full tilt) | 5.2 | ≥ 0.5 | PASS |
| Mirror plate | pad column P3 (incl. root fillet) clear of vents | 18.84 | ≥ 1 | PASS |
| Mirror plate | arm-root fillet (R8) ends inboard of the lateral post | 19.08 | ≥ 0 | PASS |
| Mirror plate | cap above pull insert hole | 2.5 | ≥ 2 | PASS |
| Mirror plate | wall around clip insert C1 | 3.2 | ≥ 2 | PASS |
| Mirror plate | wall around clip insert C2 | 3.2 | ≥ 2 | PASS |
| Mirror plate | wall around clip insert C3 | 3.2 | ≥ 2 | PASS |
| Mirror plate | clip insert hole depth within post | 34.5 | ≥ 2 | PASS |
| Clip | wall around screw hole | 3.5 | ≥ 2 | PASS |
| Clip | gap between clip and mirror face | 0.8 | ≥ 0.5 | PASS |
| Clip | clip-screw thread engagement | 6.52 | ≥ 4.8 | PASS |
| Clip | clip-screw tip vs hole depth | 6.52 | ≤ 7 | PASS |
| Push-pull | pull-bolt engagement at max gap (14.1 mm) | 8 | ≥ 8 | PASS |
| Push-pull | pull-bolt tip depth at min gap (10.1 mm) | 12 | ≤ 13 | PASS |
| Push-pull | push-bolt length left for jam nut at max gap | 5.7 | ≥ 5 | PASS |
| Push-pull | min plate gap at full travel | 10.05 | ≥ 5 | PASS |
| Push-pull | pair spacing (pull washer to push-boss root fillet) | 0.85 | ≥ 0.5 | PASS |
| Fan | fan-screw tip protrusion past plate front (must clear mirror plate) | 5.1 | ≤ 9.05 | PASS |
| Fan | fan-screw thread engagement in the plate (#6 thread-forming) | 8 | ≥ 5.27 | PASS |
| Assembly | radial clearance to tube, worst of 8 poses at ±2 mm per pair (2.3° max tilt, pose +−+); needs tube ID ≥ 234.6 mm (9.24") | 10.73 | ≥ 1 | PASS |
| Assembly | axial gap mirror plate ↔ rear plate, worst pose (+−−) | 8.04 | ≥ 1 | PASS |
| Assembly | gap mirror plate ↔ fan-screw tips, worst pose | 4.26 | ≥ 0.5 | PASS |
| Push-pull | pull-bolt tilt room in rear-plate hole at 2.3° | 0.33 | ≥ 0.1 | PASS |
| Assembly | mirror edge to lateral post gap | 0.75 | ≥ 0.25 | PASS |
| Assembly | rear plate radial fit clearance | 0.3 | ≥ 0.1 | PASS |

## Strength (hand calculations, sustained allowables for printed PETG/ASA)
| Load case | Item | Value | Allowable | Utilisation | Result |
|---|---|---|---|---|---|
| Tube horizontal: 50.9 N lateral (mirror 2.59 kg × 2) | lateral post root bending, across layers (11 × 16 mm post, load 25 mm up) | 4.93 MPa | 5 MPa | 99% | PASS |
| Tube horizontal: 50.9 N lateral (mirror 2.59 kg × 2) | arm bending at the post (18.3 × 7 mm arm + 6 × 4 mm rib) | 10 MPa | 10 MPa | 100% | PASS |
| Tube horizontal: 50.9 N lateral (mirror 2.59 kg × 2) | pull-bolt bending across the gap (steel, 1/4-20 root Ø4.79) | 25.24 MPa | 250 MPa | 10% | PASS |
| Tube vertical: preload 100 N + 18.5 N weight share per pair | pull-bolt insert pull-out (mirror plate, 1/4-20) | 118.45 N | 500 N | 24% | PASS |
| Tube vertical: preload 100 N + 18.5 N weight share per pair | push-bolt insert pull-out (rear plate, 1/4-20) | 118.45 N | 500 N | 24% | PASS |
| Tube vertical: preload 100 N + 18.5 N weight share per pair | push-bolt load on mirror plate through the Ø12.7 wear washer | 1.16 MPa | 15 MPa | 8% | PASS |
| Tube vertical: preload 100 N + 18.5 N weight share per pair | pull-bolt washer bearing on rear plate | 0.74 MPa | 15 MPa | 5% | PASS |
| Tube vertical: preload 100 N + 18.5 N weight share per pair | mirror plate local bending at each pair (t = 7 mm) | 9.07 MPa | 10 MPa | 91% | PASS |
| Tube vertical: preload 100 N + 18.5 N weight share per pair | rear plate local bending at each pair (t = 8 mm) | 6.94 MPa | 10 MPa | 69% | PASS |
| Tube vertical: preload 100 N + 18.5 N weight share per pair | rear plate spokes carrying the mirror side to the tube (3 × 24 mm wide) | 4.62 MPa | 10 MPa | 46% | PASS |
| Tube vertical: preload 100 N + 18.5 N weight share per pair | tube-screw bearing in the skirt (3 × 1/4-20, cell 3.27 kg) | 0.36 MPa | 15 MPa | 2% | PASS |
| Tube pointing down: 17 N on each clip | clip bending over the post edge (16 × 3 mm) | 1.99 MPa | 10 MPa | 20% | PASS |
| Tube pointing down: 17 N on each clip | clip-screw insert pull-out (#6-32, incl. prying) | 23.91 N | 250 N | 10% | PASS |

## Interference (CAD boolean intersection of every pair of bodies)
| Body A | Body B | Overlap volume (mm³) | Result |
|---|---|---|---|
| Rear tube plate | Mirror plate | 0 | PASS |
| Rear tube plate | Mirror clip | 0 | PASS |
| Rear tube plate | Mirror | 0 | PASS |
| Rear tube plate | Tube | 0 | PASS |
| Rear tube plate | Fan | 0 | PASS |
| Rear tube plate | Bolts, nuts & washers | 0 | PASS |
| Mirror plate | Mirror clip | 0 | PASS |
| Mirror plate | Mirror | 0 | PASS |
| Mirror plate | Tube | 0 | PASS |
| Mirror plate | Fan | 0 | PASS |
| Mirror plate | Bolts, nuts & washers | 0 | PASS |
| Mirror clip | Mirror | 0 | PASS |
| Mirror clip | Tube | 0 | PASS |
| Mirror clip | Fan | 0 | PASS |
| Mirror clip | Bolts, nuts & washers | 0 | PASS |
| Mirror | Tube | 0 | PASS |
| Mirror | Fan | 0 | PASS |
| Mirror | Bolts, nuts & washers | 0 | PASS |
| Tube | Fan | 0 | PASS |
| Tube | Bolts, nuts & washers | 0 | PASS |
| Fan | Bolts, nuts & washers | 0 | PASS |
| Mirror side tilted (worst of 8 poses, 2.3° max) | Tube | 0 | PASS |
| Mirror side tilted (worst of 8 poses, 2.3° max) | Rear tube plate | 0 | PASS |

## Print bed fit (235 × 235 mm)
| Part | Footprint (mm) | Height (mm) | Fits |
|---|---|---|---|
| Rear tube plate | 223 × 222.2 | 21.5 | yes |
| Mirror plate | 197.4 × 197.4 | 48.8 | yes |
| Mirror clip | 14.8 × 16 | 3 | yes |

## Print settings (embedded in the 3MF)
5 walls/perimeters, 40% gyroid infill, 5 top and 5 bottom layers, 0.2 mm layers, no supports. Material: PETG or ASA (avoid PLA: it creeps under the constant bolt load and softens in a hot car).

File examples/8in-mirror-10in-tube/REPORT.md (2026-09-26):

# Mirror cell: 8" mirror in 254 mm (10") ID tube

Retention: **clips** · Fan: **80 mm** · Push-pull: **3 × 1/4-20 pairs** · Bed: 235 mm

## Key dimensions (mm)
| Group | Dimension | Value |
|---|---|---|
| Rear plate | Style | full ring (plate + skirt) |
| Rear plate | Outside diameter (tube ID − fit) | 253.4 mm (9.976") |
| Rear plate | Skirt inside diameter | 234.6 mm (9.236") |
| Rear plate | Overall height (skirt + plate) | 21.5 mm (0.846") |
| Rear plate | Plate thickness (sized) | 8 mm = max(rule 8, preload 7, spokes 4) |
| Rear plate | Push boss Ø × height | 14.4 × 12 mm |
| Push-pull | Bolt size | 1/4-20 |
| Push-pull | Pair circle diameter | 132.1 mm (5.2") |
| Push-pull | Pull-to-push spacing (chord) | 17.5 mm (15.23°) |
| Push-pull | Nominal plate gap | 12.05 mm (±2 mm travel) |
| Push-pull | Max tilt at full travel (one pair out, two in) | 2.31° |
| Mirror plate | Inside fillets: pad roots / post inner faces / rib sides / arm roots (in plane) | 2 / 3 / 2 / 8 mm |
| Rear plate | Inside fillets: skirt joint / boss roots / window corners | 3 / 1.5 / 4 mm |
| Mirror plate | Core diameter | 156.5 mm (6.161") |
| Mirror plate | Span across posts | 226.7 mm (8.925") |
| Mirror plate | Base thickness (sized) | 7 mm — governed by push-pull preload (rule 6, preload 7) |
| Mirror plate | Arm rib (width × height) | 6 × 4 mm |
| Mirror plate | Lateral post depth (sized) | 11 mm (minimum 11) |
| Loads | Mirror mass (glass at 2.5 g/cm³) | 2.59 kg |
| Loads | Push-pull lock preload / torque | 100 N per bolt ≈ 0.13 N·m (finger-snug) |
| Mirror plate | Pad Ø × height above base | 14.4 × 9 mm |
| Mirror plate | Post top above mirror-plate rear face | 48.8 mm |
| Mirror | Diameter / thickness | 203.2 / 32 mm |
| Mirror | Mirror face above tube end | 81.6 mm (3.211") |
| Assembly | Overall cell height | 85.4 mm (3.36") |

## Hole schedule
| Part | Label | Qty | Feature | Size | Location | Install |
|---|---|---|---|---|---|---|
| Rear plate | A | 3 | 1/4-20 heat-set insert (push bolt) | Ø7.6 thru boss (12 tall) | R66.04 @ 105.2°, 225.2°, 345.2° | from rear face |
| Rear plate | B | 3 | 1/4-20 clearance (pull bolt) | Ø7 thru | R66.04 @ 90°, 210°, 330° |  |
| Rear plate | C | 6 | 1/4-20 heat-set insert (tube screw), radial teardrop | Ø7.6 thru skirt (9.4) | 30°, 90°, 150°, 210°, 270°, 330°; 6.75 from tube end | from outside of skirt |
| Rear plate | D | 4 | #6 thread-forming screw pilot (fan) | Ø2.8 thru | 71.5 × 71.5 square, rotated 22° | screw in from rear face |
| Rear plate | E | 1 | Fan opening | Ø76 thru | centre |  |
| Rear plate | F | 3 | Vent window (annular sector) | R59.6–R113.3, 83.3° wide | 116.3°–199.6°, 236.3°–319.6°, 356.3°–79.6° |  |
| Mirror plate | G | 3 | 1/4-20 heat-set insert (pull bolt), blind | Ø7.6 × 13.5 deep | R66.04 @ 90°, 210°, 330° | from rear face (bed side) |
| Mirror plate | H | 3 | #6-32 heat-set insert (clip), blind | Ø4 × 7.3 deep | R107.85 @ 90°, 210°, 330° | from top of post |
| Mirror plate | M | 3 | Wear-washer locating mark (push-bolt contact) | Ø1 × 1 deep | R66.04 @ 105.2°, 225.2°, 345.2° | rear face (bed side) |
| Mirror plate | I | 1 | Central vent | Ø76 thru | centre |  |
| Mirror plate | J | 3 | Vent hole | Ø32 thru | R58.12 @ 157.6°, 277.6°, 37.6° |  |
| Clip | K | 3 | #6-32 clearance | Ø4 thru | 9.25 from inner end |  |

## Bill of materials (per cell)
| Ref | Category | Qty | Description | Size / spec | Length | Used in | Notes |
|---|---|---|---|---|---|---|---|
| P1 | Printed part | 1 | Rear tube plate | PETG or ASA; Ø253.4 × 21.5 mm |  | tube end | 5 walls, 40% gyroid, 0.2 mm layers, no supports; footprint 253.4 × 253.4 mm (exceeds 235 mm bed); solid volume 300.9 cm³ |
| P2 | Printed part | 1 | Mirror plate | PETG or ASA; 226.7 mm across posts × 48.8 mm tall |  | carries the mirror | 5 walls, 40% gyroid, 0.2 mm layers, no supports; footprint 197.4 × 197.4 mm; solid volume 127.7 cm³ |
| P3 | Printed part | 3 | Mirror clip | PETG or ASA; 14.8 × 16 × 3 mm |  | clip posts | 5 walls, 40% gyroid, 0.2 mm layers, no supports; footprint 14.8 × 16 mm; solid volume 0.7 cm³ |
| S1 | Screw | 3 | Socket head cap screw (pull / adjust) | 1/4-20 | 1-1/4" | rear plate → mirror plate pad inserts | a thumbscrew or knob of the same length also works; lock at ≈ 0.13 N·m |
| S2 | Screw | 3 | Socket head cap screw (push / lock) | 1/4-20 | 1-1/4" | rear-plate push bosses | fully threaded; lock at ≈ 0.13 N·m |
| S3 | Screw | 6 | Button head socket cap screw (tube attachment) | 1/4-20 | 1/2" | through tube wall into skirt | sized for a 3.18 mm tube wall |
| S4 | Screw | 3 | Socket head cap screw (clips) | #6-32 | 3/8" | clips → clip posts |  |
| S5 | Screw | 4 | Thread-forming screw for plastics, pan head (fan mount) | #6 | 1-1/2" | fan → rear plate pilot holes | e.g. Hi-Lo or 48° plastic-forming thread; Ø2.8 mm pilot holes; don't overtighten |
| N1 | Nut / washer | 3 | Hex jam nut | 1/4-20 |  | push bolts | 7/16" across flats |
| N2 | Nut / washer | 3 | Flat washer, SAE | 1/4-20 |  | under pull-bolt heads | Ø15.9 mm OD |
| N3 | Nut / washer | 3 | Steel flat washer (wear pad for the push-bolt tip) | #10 SAE (≈ Ø12.7 OD, Ø5.6 hole, 1.2 thick) |  | cemented to the mirror plate rear face at the Ø1 marks | hole must be smaller than the Ø6.4 bolt tip; epoxy or CA |
| I1 | Heat-set insert | 12 | Brass heat-set insert (tapered, for plastics) | 1/4-20, 8 mm long, for Ø7.6 mm hole |  | rear plate, push bosses; mirror plate, pad columns; rear-plate skirt (radial) | install from rear face; install from outside |
| I2 | Heat-set insert | 3 | Brass heat-set insert (tapered, for plastics) | #6-32, 4.8 mm long, for Ø4 mm hole |  | clip posts | install from top of post |
| F1 | Fan | 1 | 80 mm 12 V DC fan | 8025 (80 × 80 × 25 mm), 71.5 mm hole spacing |  | rear face of rear plate | blows into the tube; 12 V supply and lead not included |
| C1 | Consumable | 1 | Filament | PETG or ASA |  | all printed parts | PLA not recommended (creeps under bolt load) |
| T1 | Tool | 1 | Hex key | 3/16" |  | 1/4-20 socket heads |  |
| T2 | Tool | 1 | Hex key | 5/32" |  | 1/4-20 button heads |  |
| T3 | Tool | 1 | Hex key | 7/64" |  | #6-32 clip screws |  |
| T4 | Tool | 1 | Wrench | 7/16" |  | push-bolt jam nuts |  |
| T5 | Tool | 1 | Screwdriver | Phillips #2 |  | #6 fan screws |  |
| T6 | Tool | 1 | Drill bit | 17/64" (6.7 mm) |  | 6 tube-wall holes for 1/4-20 | positions are in the hole schedule (C) |
| T7 | Tool | 1 | Soldering iron with heat-set insert tips | 1/4-20, #6-32 |  | installing inserts | or a dedicated insert press |

## Checks
| Part | Check | Value (mm) | Required | Result |
|---|---|---|---|---|
| Rear plate | wall around pull clearance hole P1 | 8.43 | ≥ 2 | PASS |
| Rear plate | wall around push insert P1 | 3 | ≥ 2 | PASS |
| Rear plate | wall around pull clearance hole P2 | 8.43 | ≥ 2 | PASS |
| Rear plate | wall around push insert P2 | 3 | ≥ 2 | PASS |
| Rear plate | wall around pull clearance hole P3 | 8.43 | ≥ 2 | PASS |
| Rear plate | wall around push insert P3 | 3 | ≥ 2 | PASS |
| Rear plate | wall around fan screw pilot F1 | 7.26 | ≥ 2 | PASS |
| Rear plate | wall around fan screw pilot F2 | 7.26 | ≥ 2 | PASS |
| Rear plate | wall around fan screw pilot F3 | 7.26 | ≥ 2 | PASS |
| Rear plate | wall around fan screw pilot F4 | 10.8 | ≥ 2 | PASS |
| Rear plate | solid bearing under pull washer P1 | 3.98 | ≥ 0.5 | PASS |
| Rear plate | push boss P1 (incl. root fillet) clear of cut-outs | 3.98 | ≥ 0.5 | PASS |
| Rear plate | solid bearing under pull washer P2 | 3.98 | ≥ 0.5 | PASS |
| Rear plate | push boss P2 (incl. root fillet) clear of cut-outs | 3.98 | ≥ 0.5 | PASS |
| Rear plate | solid bearing under pull washer P3 | 3.98 | ≥ 0.5 | PASS |
| Rear plate | push boss P3 (incl. root fillet) clear of cut-outs | 3.98 | ≥ 0.5 | PASS |
| Rear plate | wall: tube-screw insert to skirt edge | 2.55 | ≥ 2 | PASS |
| Rear plate | skirt thickness ≥ tube insert length | 1.4 | ≥ 0 | PASS |
| Rear plate | push insert fits boss height | 4 | ≥ 0 | PASS |
| Rear plate | wall between tube-screw inserts | 118.3 | ≥ 2 | PASS |
| Mirror plate | wall around pull insert P1 | 3 | ≥ 2 | PASS |
| Mirror plate | wall around pull insert P2 | 3 | ≥ 2 | PASS |
| Mirror plate | wall around pull insert P3 | 3 | ≥ 2 | PASS |
| Mirror plate | wear-washer seat P1 on solid plastic (Ø12.7, incl. 0.6 mm slide at full tilt) | 5.2 | ≥ 0.5 | PASS |
| Mirror plate | push-bolt tip (Ø6.35) larger than the wear-washer hole (Ø5.6) | 0.75 | ≥ 0.3 | PASS |
| Mirror plate | pad column P1 (incl. root fillet) clear of vents | 18.84 | ≥ 1 | PASS |
| Mirror plate | wear-washer seat P2 on solid plastic (Ø12.7, incl. 0.6 mm slide at full tilt) | 5.2 | ≥ 0.5 | PASS |
| Mirror plate | pad column P2 (incl. root fillet) clear of vents | 18.84 | ≥ 1 | PASS |
| Mirror plate | wear-washer seat P3 on solid plastic (Ø12.7, incl. 0.6 mm slide at full tilt) | 5.2 | ≥ 0.5 | PASS |
| Mirror plate | pad column P3 (incl. root fillet) clear of vents | 18.84 | ≥ 1 | PASS |
| Mirror plate | arm-root fillet (R8) ends inboard of the lateral post | 19.08 | ≥ 0 | PASS |
| Mirror plate | cap above pull insert hole | 2.5 | ≥ 2 | PASS |
| Mirror plate | wall around clip insert C1 | 3.2 | ≥ 2 | PASS |
| Mirror plate | wall around clip insert C2 | 3.2 | ≥ 2 | PASS |
| Mirror plate | wall around clip insert C3 | 3.2 | ≥ 2 | PASS |
| Mirror plate | clip insert hole depth within post | 34.5 | ≥ 2 | PASS |
| Clip | wall around screw hole | 3.5 | ≥ 2 | PASS |
| Clip | gap between clip and mirror face | 0.8 | ≥ 0.5 | PASS |
| Clip | clip-screw thread engagement | 6.52 | ≥ 4.8 | PASS |
| Clip | clip-screw tip vs hole depth | 6.52 | ≤ 7 | PASS |
| Push-pull | pull-bolt engagement at max gap (14.1 mm) | 8 | ≥ 8 | PASS |
| Push-pull | pull-bolt tip depth at min gap (10.1 mm) | 12 | ≤ 13 | PASS |
| Push-pull | push-bolt length left for jam nut at max gap | 5.7 | ≥ 5 | PASS |
| Push-pull | min plate gap at full travel | 10.05 | ≥ 5 | PASS |
| Push-pull | pair spacing (pull washer to push-boss root fillet) | 0.85 | ≥ 0.5 | PASS |
| Fan | fan-screw tip protrusion past plate front (must clear mirror plate) | 5.1 | ≤ 9.05 | PASS |
| Fan | fan-screw thread engagement in the plate (#6 thread-forming) | 8 | ≥ 5.27 | PASS |
| Assembly | radial clearance to tube, worst of 8 poses at ±2 mm per pair (2.3° max tilt, pose +−+); needs tube ID ≥ 234.6 mm (9.24") | 10.73 | ≥ 1 | PASS |
| Assembly | axial gap mirror plate ↔ rear plate, worst pose (+−−) | 8.04 | ≥ 1 | PASS |
| Assembly | gap mirror plate ↔ fan-screw tips, worst pose | 4.26 | ≥ 0.5 | PASS |
| Push-pull | pull-bolt tilt room in rear-plate hole at 2.3° | 0.33 | ≥ 0.1 | PASS |
| Assembly | mirror edge to lateral post gap | 0.75 | ≥ 0.25 | PASS |
| Assembly | rear plate radial fit clearance | 0.3 | ≥ 0.1 | PASS |

## Strength (hand calculations, sustained allowables for printed PETG/ASA)
| Load case | Item | Value | Allowable | Utilisation | Result |
|---|---|---|---|---|---|
| Tube horizontal: 50.9 N lateral (mirror 2.59 kg × 2) | lateral post root bending, across layers (11 × 16 mm post, load 25 mm up) | 4.93 MPa | 5 MPa | 99% | PASS |
| Tube horizontal: 50.9 N lateral (mirror 2.59 kg × 2) | arm bending at the post (18.3 × 7 mm arm + 6 × 4 mm rib) | 10 MPa | 10 MPa | 100% | PASS |
| Tube horizontal: 50.9 N lateral (mirror 2.59 kg × 2) | pull-bolt bending across the gap (steel, 1/4-20 root Ø4.79) | 25.24 MPa | 250 MPa | 10% | PASS |
| Tube vertical: preload 100 N + 18.5 N weight share per pair | pull-bolt insert pull-out (mirror plate, 1/4-20) | 118.45 N | 500 N | 24% | PASS |
| Tube vertical: preload 100 N + 18.5 N weight share per pair | push-bolt insert pull-out (rear plate, 1/4-20) | 118.45 N | 500 N | 24% | PASS |
| Tube vertical: preload 100 N + 18.5 N weight share per pair | push-bolt load on mirror plate through the Ø12.7 wear washer | 1.16 MPa | 15 MPa | 8% | PASS |
| Tube vertical: preload 100 N + 18.5 N weight share per pair | pull-bolt washer bearing on rear plate | 0.74 MPa | 15 MPa | 5% | PASS |
| Tube vertical: preload 100 N + 18.5 N weight share per pair | mirror plate local bending at each pair (t = 7 mm) | 9.07 MPa | 10 MPa | 91% | PASS |
| Tube vertical: preload 100 N + 18.5 N weight share per pair | rear plate local bending at each pair (t = 8 mm) | 6.94 MPa | 10 MPa | 69% | PASS |
| Tube vertical: preload 100 N + 18.5 N weight share per pair | rear plate spokes carrying the mirror side to the skirt (73 mm wide) | 1.53 MPa | 10 MPa | 15% | PASS |
| Tube vertical: preload 100 N + 18.5 N weight share per pair | tube-screw bearing in the skirt (6 × 1/4-20, cell 3.66 kg) | 0.2 MPa | 15 MPa | 1% | PASS |
| Tube pointing down: 17 N on each clip | clip bending over the post edge (16 × 3 mm) | 1.99 MPa | 10 MPa | 20% | PASS |
| Tube pointing down: 17 N on each clip | clip-screw insert pull-out (#6-32, incl. prying) | 23.91 N | 250 N | 10% | PASS |

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

## Print bed fit (235 × 235 mm)
| Part | Footprint (mm) | Height (mm) | Fits |
|---|---|---|---|
| Rear tube plate | 253.4 × 253.4 | 21.5 | **NO – see oversize policy** |
| Mirror plate | 197.4 × 197.4 | 48.8 | yes |
| Mirror clip | 14.8 × 16 | 3 | yes |

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

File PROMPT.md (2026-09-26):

# Mirror Cell Design App — Design Brief

Build a browser-based application that helps me design 3D-printable model files
for a mirror cell for a Newtonian telescope.

Where a point below says **"Decide and state"**, make a reasonable choice, write
it down (in the README and/or the app UI), and implement to it — do not leave it
implicit.

## 1. Deliverables

- A complete HTML/JavaScript app (see §5 for packaging constraints).
- A `README.md` documenting the design decisions and how to use the app.
- Example exports: one mirror cell for a 6" mirror in an 8" ID tube, and one for
  an 8" mirror in a 10" ID tube.

## 2. Supported configurations

- Mirror diameters are chosen from presets: **4.25", 6", 8", 10"**.
- Tube inner diameter is entered as a value.
- Mirror thickness is entered as a value.

## 3. Mechanical design

- Two major parts:
  - a **rear tube plate** sized to match the inside diameter of the tube, and
  - a **mirror plate** that holds the mirror.
- The two parts are joined by a **push-pull** arrangement consisting of **three
  pairs** of push-pull bolts.
- Prefer **imperial** bolt sizes; assume **heat-set inserts** are used where
  appropriate.
- Ensure at least **2 mm of wall thickness** around every heat-set insert
  location, and adequate material around all through holes and insert holes.
- Mirror retention is selectable: either **RTV glue** or **clips**.
- Optional **cooling fan** for the mirror.

## 4. Outputs, previews and checks

- A **live 3D preview** of the assembly, with the mirror ghosted.
- A **dimensioned 2D layout view**.
- Export to both **STEP** and **3MF**.
  - 3MF exports use appropriate defaults for wall count and infill (**Decide and
    state** the values).
- Parts are oriented to print **without supports**.
- Warn the user when any part exceeds a standard **220 × 220 mm** bed.
  - **Decide and state** how oversize configurations are handled (e.g. 10" ID
    plates exceed this bed), and reflect that choice in the warning.

## 5. Implementation constraints

- Use a browser-based CAD kernel such as **replicad** or **jscad**. Choose by
  best judgement; other packages are fine if they suit the application better
  (**Decide and state** the kernel).
- Ship as a **single self-contained HTML file** that opens directly from
  `file://` with **no build process**. Any third-party dependencies are loaded
  from a **CDN**, so the first load requires an internet connection.

## 6. Definition of done

- All necessary dimensions are specified for the finished model.
- All parts assemble without interference.
- All through holes and insert holes have the required wall thickness.
- The STEP and 3MF files are downloadable from the app.

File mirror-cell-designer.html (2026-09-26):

# Mirror Cell Designer

Starting…

◐

Mirror

4.25″6″8″10″

Mirror thickness Tube Tube inside diameter Tube wall thickness sets tube-screw length only Rear plate 3 spokes print smaller

RingSpokes

Units for these inputs

inmm

Mirror retention

RTV glueClips

Cooling fan Fan on rear plate Printer Bed size (mm, square)

Advanced

Tube fit clearance diametral, mm Min. plate gap mm (rounded up to suit a standard bolt) Collimation travel ± mm at each pair Mirror edge gap radial, mm Clip gap above mirror mm Push-pull lock preload N per bolt; sizes the plates

Reset to preset defaults

Status

Export

All parts3MF (print)STEP (assembly)

DocsBOM .csvDrawing SVGReport .md

3D preview 2D layout Checks Dimensions & BOM Design decisions

Loading the CAD kernel from the CDN…
(about 23 MB the first time; cached afterwards)

AssemblyPrint layout

Hardware Tube Section Explode Fit view

Dimensioned layout generated from the same numbers as the solids. All dimensions in mm. Hole letters refer to the hole schedule on the Dimensions & BOM tab.

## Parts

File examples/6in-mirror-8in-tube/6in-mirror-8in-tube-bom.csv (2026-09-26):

Ref | Category | Qty | Description | Size / spec | Length | Used in | Notes | Configuration
P1 | Printed part | 1 | Rear tube plate | PETG or ASA; Ø202.6 × 18 mm |  | tube end | 5 walls, 40% gyroid, 0.2 mm layers, no supports; footprint 202.5 × 202.5 mm; solid volume 169.6 cm³ | 6" × 25.4 mm mirror, 203.2 mm (8") ID tube, RTV, 60 mm fan, 3 × #10-24 push-pull pairs
P2 | Printed part | 1 | Mirror plate | PETG or ASA; 169.9 mm across posts × 28.1 mm tall |  | carries the mirror | 5 walls, 40% gyroid, 0.2 mm layers, no supports; footprint 148.9 × 148.9 mm; solid volume 67.1 cm³ | 6" × 25.4 mm mirror, 203.2 mm (8") ID tube, RTV, 60 mm fan, 3 × #10-24 push-pull pairs
S1 | Screw | 3 | Socket head cap screw (pull / adjust) | #10-24 | 1-1/4" | rear plate → mirror plate pad inserts | a thumbscrew or knob of the same length also works; lock at ≈ 0.1 N·m | 6" × 25.4 mm mirror, 203.2 mm (8") ID tube, RTV, 60 mm fan, 3 × #10-24 push-pull pairs
S2 | Screw | 3 | Socket head cap screw (push / lock) | #10-24 | 1-1/2" | rear-plate push bosses | fully threaded; lock at ≈ 0.1 N·m | 6" × 25.4 mm mirror, 203.2 mm (8") ID tube, RTV, 60 mm fan, 3 × #10-24 push-pull pairs
S3 | Screw | 6 | Button head socket cap screw (tube attachment) | #10-24 | 1/2" | through tube wall into skirt | sized for a 3.18 mm tube wall | 6" × 25.4 mm mirror, 203.2 mm (8") ID tube, RTV, 60 mm fan, 3 × #10-24 push-pull pairs
S4 | Screw | 4 | Thread-forming screw for plastics, pan head (fan mount) | #6 | 7/8" | fan → rear plate pilot holes | e.g. Hi-Lo or 48° plastic-forming thread; Ø2.8 mm pilot holes; don't overtighten | 6" × 25.4 mm mirror, 203.2 mm (8") ID tube, RTV, 60 mm fan, 3 × #10-24 push-pull pairs
N1 | Nut / washer | 3 | Hex jam nut | #10-24 |  | push bolts | 3/8" across flats | 6" × 25.4 mm mirror, 203.2 mm (8") ID tube, RTV, 60 mm fan, 3 × #10-24 push-pull pairs
N2 | Nut / washer | 3 | Flat washer, SAE | #10-24 |  | under pull-bolt heads | Ø12.7 mm OD | 6" × 25.4 mm mirror, 203.2 mm (8") ID tube, RTV, 60 mm fan, 3 × #10-24 push-pull pairs
N3 | Nut / washer | 3 | Steel flat washer (wear pad for the push-bolt tip) | #6 SAE (≈ Ø9.5 OD, Ø4 hole, 1.2 thick) |  | cemented to the mirror plate rear face at the Ø1 marks | hole must be smaller than the Ø4.8 bolt tip; epoxy or CA | 6" × 25.4 mm mirror, 203.2 mm (8") ID tube, RTV, 60 mm fan, 3 × #10-24 push-pull pairs
I1 | Heat-set insert | 12 | Brass heat-set insert (tapered, for plastics) | #10-24, 6.4 mm long, for Ø5.6 mm hole |  | rear plate, push bosses; mirror plate, pad columns; rear-plate skirt (radial) | install from rear face; install from outside | 6" × 25.4 mm mirror, 203.2 mm (8") ID tube, RTV, 60 mm fan, 3 × #10-24 push-pull pairs
F1 | Fan | 1 | 60 mm 12 V DC fan | 6015 (60 × 60 × 15 mm), 50 mm hole spacing |  | rear face of rear plate | blows into the tube; 12 V supply and lead not included | 6" × 25.4 mm mirror, 203.2 mm (8") ID tube, RTV, 60 mm fan, 3 × #10-24 push-pull pairs
C1 | Consumable | 1 | Neutral-cure silicone RTV | alkoxy/oxime cure — not acetic (vinegar-smelling) |  | pad cups | 3 blobs, 2 mm thick | 6" × 25.4 mm mirror, 203.2 mm (8") ID tube, RTV, 60 mm fan, 3 × #10-24 push-pull pairs
C2 | Consumable | 1 | Filament | PETG or ASA |  | all printed parts | PLA not recommended (creeps under bolt load) | 6" × 25.4 mm mirror, 203.2 mm (8") ID tube, RTV, 60 mm fan, 3 × #10-24 push-pull pairs
T1 | Tool | 1 | Hex key | 5/32" |  | #10-24 socket heads |  | 6" × 25.4 mm mirror, 203.2 mm (8") ID tube, RTV, 60 mm fan, 3 × #10-24 push-pull pairs
T2 | Tool | 1 | Hex key | 1/8" |  | #10-24 button heads |  | 6" × 25.4 mm mirror, 203.2 mm (8") ID tube, RTV, 60 mm fan, 3 × #10-24 push-pull pairs
T3 | Tool | 1 | Wrench | 3/8" |  | push-bolt jam nuts |  | 6" × 25.4 mm mirror, 203.2 mm (8") ID tube, RTV, 60 mm fan, 3 × #10-24 push-pull pairs
T4 | Tool | 1 | Screwdriver | Phillips #2 |  | #6 fan screws |  | 6" × 25.4 mm mirror, 203.2 mm (8") ID tube, RTV, 60 mm fan, 3 × #10-24 push-pull pairs
T5 | Tool | 1 | Drill bit | 13/64" (5.2 mm) |  | 6 tube-wall holes for #10-24 | positions are in the hole schedule (C) | 6" × 25.4 mm mirror, 203.2 mm (8") ID tube, RTV, 60 mm fan, 3 × #10-24 push-pull pairs
T6 | Tool | 1 | Soldering iron with heat-set insert tips | #10-24 |  | installing inserts | or a dedicated insert press | 6" × 25.4 mm mirror, 203.2 mm (8") ID tube, RTV, 60 mm fan, 3 × #10-24 push-pull pairs

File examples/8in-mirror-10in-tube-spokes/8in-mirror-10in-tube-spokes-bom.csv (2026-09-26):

Ref | Category | Qty | Description | Size / spec | Length | Used in | Notes | Configuration
P1 | Printed part | 1 | Rear tube plate | PETG or ASA; Ø253.4 × 21.5 mm |  | tube end | 5 walls, 40% gyroid, 0.2 mm layers, no supports; footprint 223 × 222.2 mm; solid volume 155.4 cm³ | 8" × 32 mm mirror, 254 mm (10") ID tube, clips, 80 mm fan, 3 × 1/4-20 push-pull pairs
P2 | Printed part | 1 | Mirror plate | PETG or ASA; 226.7 mm across posts × 48.8 mm tall |  | carries the mirror | 5 walls, 40% gyroid, 0.2 mm layers, no supports; footprint 197.4 × 197.4 mm; solid volume 127.7 cm³ | 8" × 32 mm mirror, 254 mm (10") ID tube, clips, 80 mm fan, 3 × 1/4-20 push-pull pairs
P3 | Printed part | 3 | Mirror clip | PETG or ASA; 14.8 × 16 × 3 mm |  | clip posts | 5 walls, 40% gyroid, 0.2 mm layers, no supports; footprint 14.8 × 16 mm; solid volume 0.7 cm³ | 8" × 32 mm mirror, 254 mm (10") ID tube, clips, 80 mm fan, 3 × 1/4-20 push-pull pairs
S1 | Screw | 3 | Socket head cap screw (pull / adjust) | 1/4-20 | 1-1/4" | rear plate → mirror plate pad inserts | a thumbscrew or knob of the same length also works; lock at ≈ 0.13 N·m | 8" × 32 mm mirror, 254 mm (10") ID tube, clips, 80 mm fan, 3 × 1/4-20 push-pull pairs
S2 | Screw | 3 | Socket head cap screw (push / lock) | 1/4-20 | 1-1/4" | rear-plate push bosses | fully threaded; lock at ≈ 0.13 N·m | 8" × 32 mm mirror, 254 mm (10") ID tube, clips, 80 mm fan, 3 × 1/4-20 push-pull pairs
S3 | Screw | 3 | Button head socket cap screw (tube attachment) | 1/4-20 | 1/2" | through tube wall into skirt | sized for a 3.18 mm tube wall | 8" × 32 mm mirror, 254 mm (10") ID tube, clips, 80 mm fan, 3 × 1/4-20 push-pull pairs
S4 | Screw | 3 | Socket head cap screw (clips) | #6-32 | 3/8" | clips → clip posts |  | 8" × 32 mm mirror, 254 mm (10") ID tube, clips, 80 mm fan, 3 × 1/4-20 push-pull pairs
S5 | Screw | 4 | Thread-forming screw for plastics, pan head (fan mount) | #6 | 1-1/2" | fan → rear plate pilot holes | e.g. Hi-Lo or 48° plastic-forming thread; Ø2.8 mm pilot holes; don't overtighten | 8" × 32 mm mirror, 254 mm (10") ID tube, clips, 80 mm fan, 3 × 1/4-20 push-pull pairs
N1 | Nut / washer | 3 | Hex jam nut | 1/4-20 |  | push bolts | 7/16" across flats | 8" × 32 mm mirror, 254 mm (10") ID tube, clips, 80 mm fan, 3 × 1/4-20 push-pull pairs
N2 | Nut / washer | 3 | Flat washer, SAE | 1/4-20 |  | under pull-bolt heads | Ø15.9 mm OD | 8" × 32 mm mirror, 254 mm (10") ID tube, clips, 80 mm fan, 3 × 1/4-20 push-pull pairs
N3 | Nut / washer | 3 | Steel flat washer (wear pad for the push-bolt tip) | #10 SAE (≈ Ø12.7 OD, Ø5.6 hole, 1.2 thick) |  | cemented to the mirror plate rear face at the Ø1 marks | hole must be smaller than the Ø6.4 bolt tip; epoxy or CA | 8" × 32 mm mirror, 254 mm (10") ID tube, clips, 80 mm fan, 3 × 1/4-20 push-pull pairs
I1 | Heat-set insert | 9 | Brass heat-set insert (tapered, for plastics) | 1/4-20, 8 mm long, for Ø7.6 mm hole |  | rear plate, push bosses; mirror plate, pad columns; rear-plate spoke tips (radial) | install from rear face; install from outside | 8" × 32 mm mirror, 254 mm (10") ID tube, clips, 80 mm fan, 3 × 1/4-20 push-pull pairs
I2 | Heat-set insert | 3 | Brass heat-set insert (tapered, for plastics) | #6-32, 4.8 mm long, for Ø4 mm hole |  | clip posts | install from top of post | 8" × 32 mm mirror, 254 mm (10") ID tube, clips, 80 mm fan, 3 × 1/4-20 push-pull pairs
F1 | Fan | 1 | 80 mm 12 V DC fan | 8025 (80 × 80 × 25 mm), 71.5 mm hole spacing |  | rear face of rear plate | blows into the tube; 12 V supply and lead not included | 8" × 32 mm mirror, 254 mm (10") ID tube, clips, 80 mm fan, 3 × 1/4-20 push-pull pairs
C1 | Consumable | 1 | Filament | PETG or ASA |  | all printed parts | PLA not recommended (creeps under bolt load) | 8" × 32 mm mirror, 254 mm (10") ID tube, clips, 80 mm fan, 3 × 1/4-20 push-pull pairs
T1 | Tool | 1 | Hex key | 3/16" |  | 1/4-20 socket heads |  | 8" × 32 mm mirror, 254 mm (10") ID tube, clips, 80 mm fan, 3 × 1/4-20 push-pull pairs
T2 | Tool | 1 | Hex key | 5/32" |  | 1/4-20 button heads |  | 8" × 32 mm mirror, 254 mm (10") ID tube, clips, 80 mm fan, 3 × 1/4-20 push-pull pairs
T3 | Tool | 1 | Hex key | 7/64" |  | #6-32 clip screws |  | 8" × 32 mm mirror, 254 mm (10") ID tube, clips, 80 mm fan, 3 × 1/4-20 push-pull pairs
T4 | Tool | 1 | Wrench | 7/16" |  | push-bolt jam nuts |  | 8" × 32 mm mirror, 254 mm (10") ID tube, clips, 80 mm fan, 3 × 1/4-20 push-pull pairs
T5 | Tool | 1 | Screwdriver | Phillips #2 |  | #6 fan screws |  | 8" × 32 mm mirror, 254 mm (10") ID tube, clips, 80 mm fan, 3 × 1/4-20 push-pull pairs
T6 | Tool | 1 | Drill bit | 17/64" (6.7 mm) |  | 3 tube-wall holes for 1/4-20 | positions are in the hole schedule (C) | 8" × 32 mm mirror, 254 mm (10") ID tube, clips, 80 mm fan, 3 × 1/4-20 push-pull pairs
T7 | Tool | 1 | Soldering iron with heat-set insert tips | 1/4-20, #6-32 |  | installing inserts | or a dedicated insert press | 8" × 32 mm mirror, 254 mm (10") ID tube, clips, 80 mm fan, 3 × 1/4-20 push-pull pairs

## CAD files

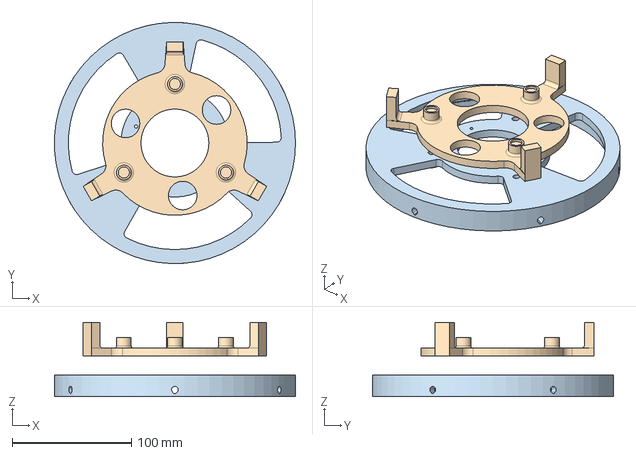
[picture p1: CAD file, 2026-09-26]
examples/6in-mirror-8in-tube/6in-mirror-8in-tube-assembly.step
202.5 x 202.6 x 62.2 mm

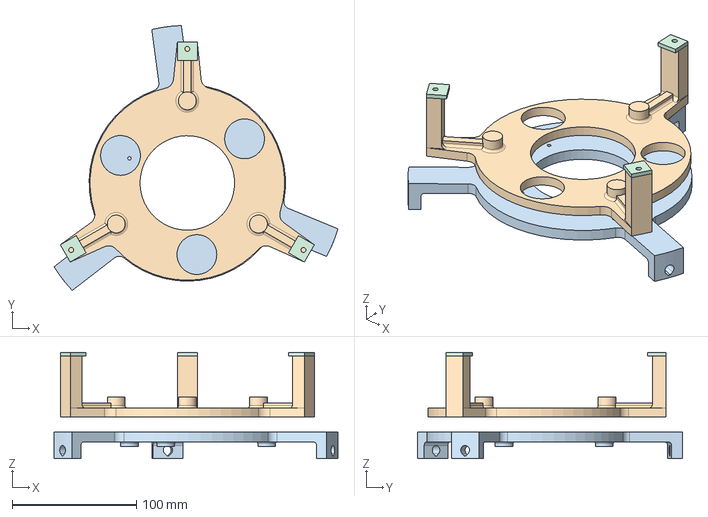
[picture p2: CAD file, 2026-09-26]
examples/8in-mirror-10in-tube-spokes/8in-mirror-10in-tube-spokes-assembly.step
228.4 x 213.1 x 85.3 mm

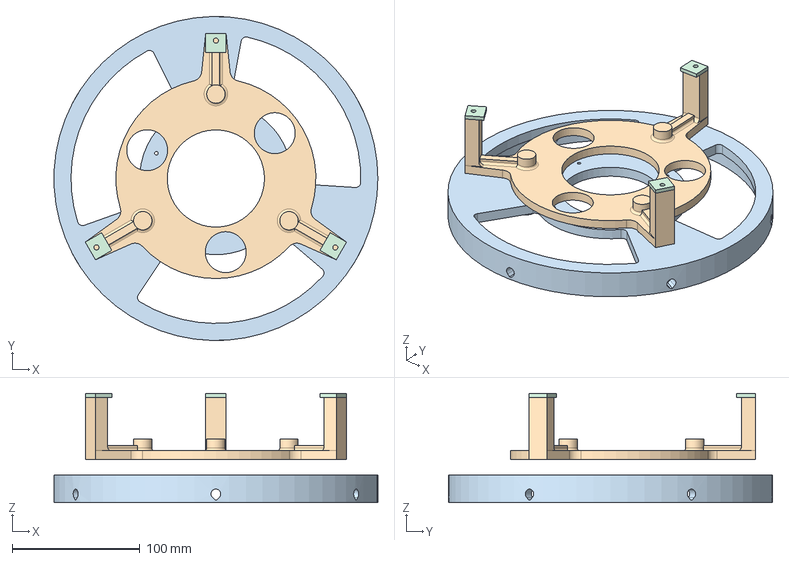
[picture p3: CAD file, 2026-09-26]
examples/8in-mirror-10in-tube/8in-mirror-10in-tube-assembly.step
253.2 x 253.4 x 85.3 mm

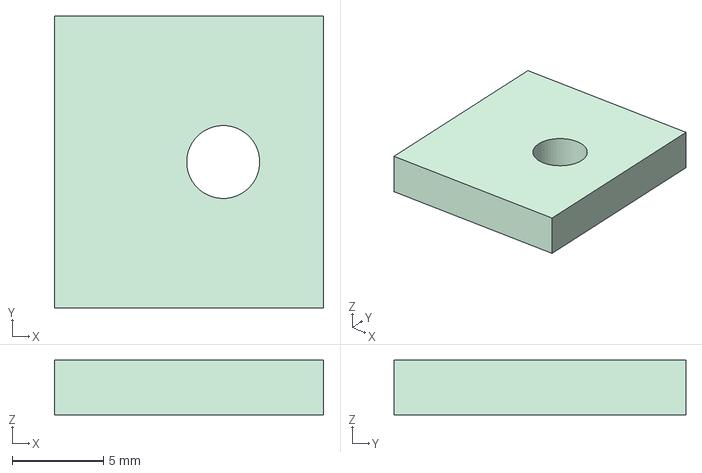
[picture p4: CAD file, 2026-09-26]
examples/8in-mirror-10in-tube-spokes/8in-mirror-10in-tube-spokes-clip-print.step
14.8 x 16.0 x 3.00 mm

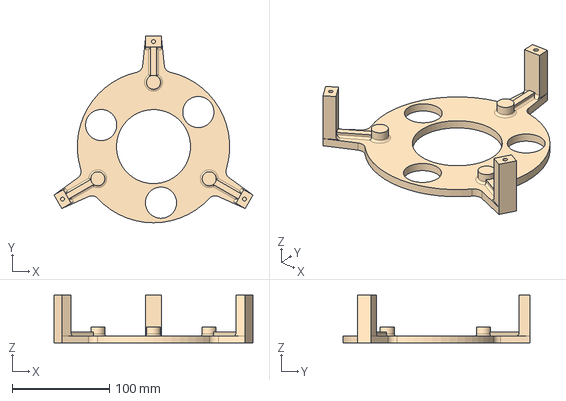
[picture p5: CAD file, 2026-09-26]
examples/8in-mirror-10in-tube/8in-mirror-10in-tube-mirror-plate-print.step
204.3 x 191.6 x 48.8 mm

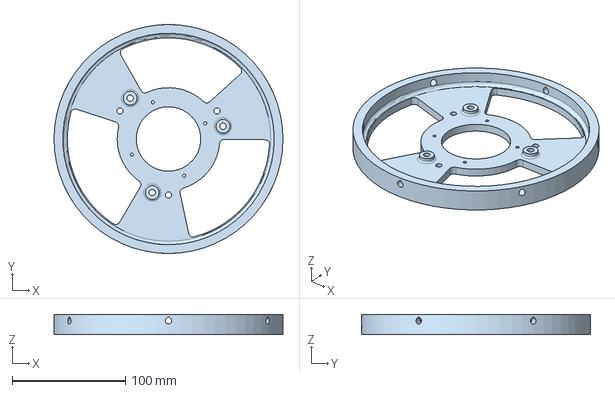
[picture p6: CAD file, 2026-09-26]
examples/6in-mirror-8in-tube/6in-mirror-8in-tube-rear-plate-print.step
202.6 x 202.6 x 18.0 mm

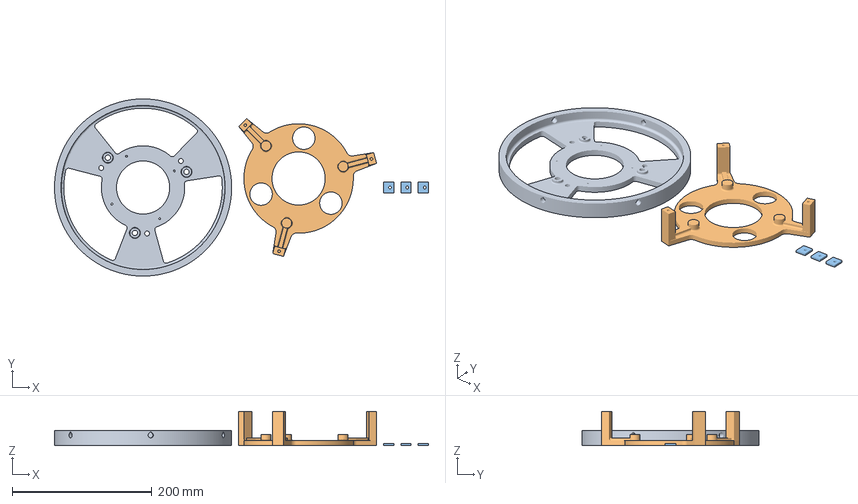
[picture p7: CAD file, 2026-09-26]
examples/8in-mirror-10in-tube/8in-mirror-10in-tube.3mf
535.0 x 253.4 x 48.8 mm
Rear tube plate
Mirror plate
Mirror clip x 3

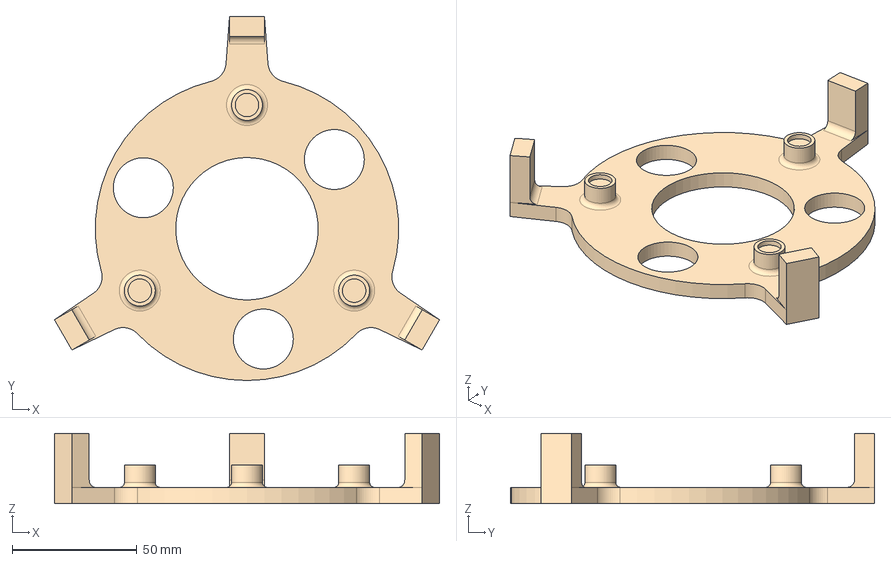
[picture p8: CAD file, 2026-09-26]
examples/6in-mirror-8in-tube/6in-mirror-8in-tube-mirror-plate-print.step
154.1 x 145.7 x 28.1 mm

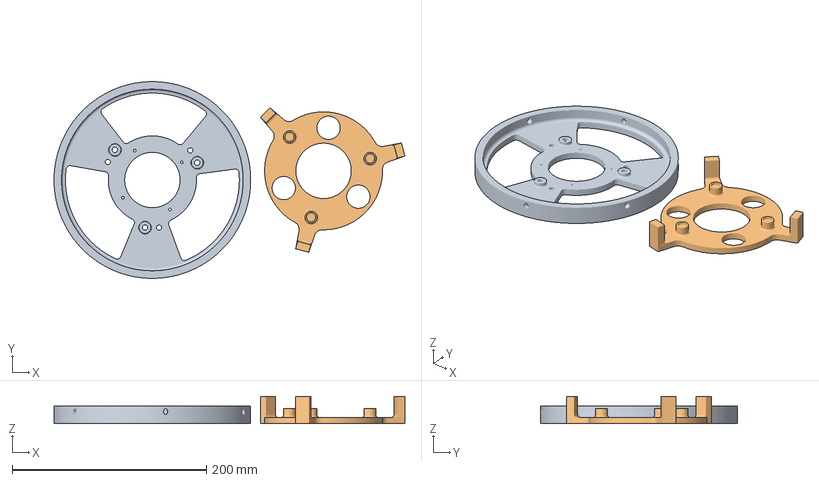
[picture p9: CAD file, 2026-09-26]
examples/6in-mirror-8in-tube/6in-mirror-8in-tube.3mf
361.4 x 202.6 x 28.1 mm
Rear tube plate
Mirror plate

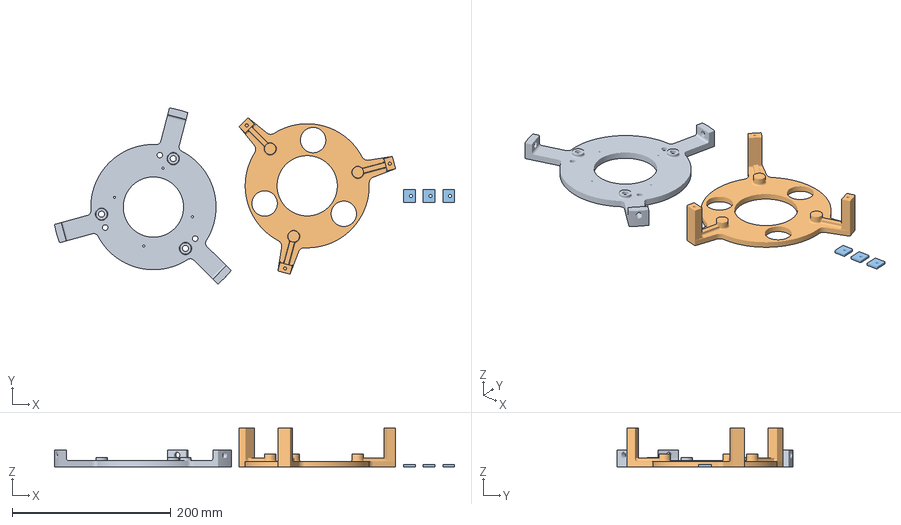
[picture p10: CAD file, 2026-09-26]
examples/8in-mirror-10in-tube-spokes/8in-mirror-10in-tube-spokes.3mf
504.6 x 222.2 x 48.8 mm
Rear tube plate
Mirror plate
Mirror clip x 3

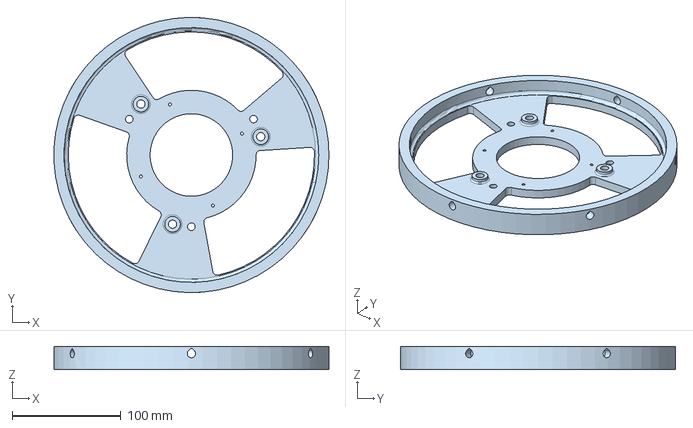
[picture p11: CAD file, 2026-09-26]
examples/8in-mirror-10in-tube/8in-mirror-10in-tube-rear-plate-print.step
253.2 x 253.4 x 21.5 mm

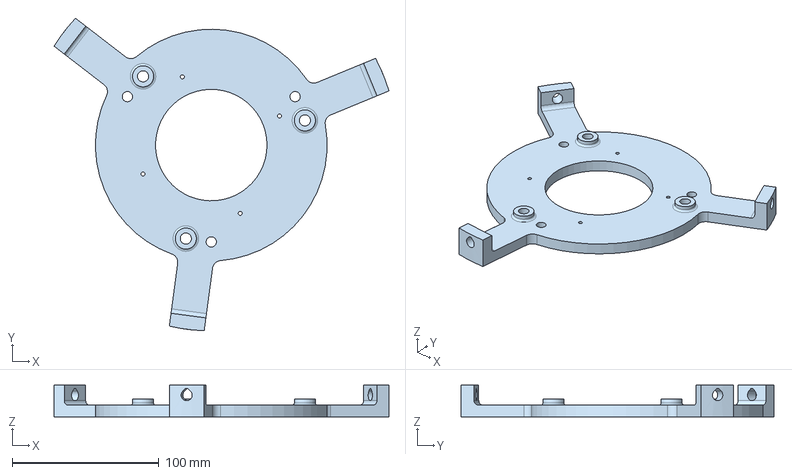
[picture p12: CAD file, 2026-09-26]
examples/8in-mirror-10in-tube-spokes/8in-mirror-10in-tube-spokes-rear-plate-print.step
228.4 x 213.1 x 21.5 mm

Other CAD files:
examples/8in-mirror-10in-tube-spokes/8in-mirror-10in-tube-spokes-mirror-plate-print.step
examples/8in-mirror-10in-tube/8in-mirror-10in-tube-clip-print.step

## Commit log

2026-09-26 Add browser-based Newtonian mirror cell designer
    Single-file HTML app (replicad/OpenCascade via CDN, no build step) that
    designs 3D-printable push-pull mirror cells for 4.25"-10" mirrors and
    exports STEP, 3MF (print settings embedded), a BOM CSV, a dimensioned
    SVG drawing and a Markdown report.
    - Rear tube plate with radial heat-set inserts, mirror plate with three
    #10-24 or 1/4-20 push-pull pairs, RTV or clip retention, optional fan
    - Geometric checks: wall thickness around every insert and hole, bolt
    engagement and travel, tube clearance over all 8 extreme collimation
    poses, plus CAD interference between every pair of bodies (nominal
    and tilted)
    - Strength hand calculations for th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
    [6in-mirror-8in-tube-assembly.step, 6in-mirror-8in-tube-bom.csv, 6in-mirror-8in-tube-mirror-plate-print.step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]
2026-09-26 Add optional 3-spoke rear plate; default bed 235 mm
    The rear plate can now be a hub with three spokes instead of a full ring.
    Each spoke is centred between its push-pull pair and ends in a pad at the
    tube wall with one radial #8-32 heat-set insert (3 tube screws total).
    For an 8" mirror in a 10" tube the rear plate shrinks from 253 mm to
    223 x 222 mm and uses about 38% less plastic.
    - Rear plate style selectable in the UI (ring stays the default)
    - Hub sized to carry the pairs and fan; fillets at spoke roots (6 mm,
    in plane) and tip pads (3 mm)
    - Wall, strength (spoke bending), interference and tilted-pose checks,
    drawing, key dimensions, hole schedule and BOM follow the style
    - Default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
    [6in-mirror-8in-tube-assembly.step, 6in-mirror-8in-tube-mirror-plate-print.step, 6in-mirror-8in-tube-rear-plate-print.step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]
2026-09-26 Use one insert size for push-pull and tube; thread-forming fan screws
    - Tube screws now match the push-pull size (#10-24 for 4.25"/6" mirrors,
    1/4-20 for 8"/10"), so both share one heat-set insert. The skirt/tip
    pads grow slightly to keep 2 mm walls; BOM gives the matching drill
    and button-head key.
    - The fan mounts with #4/#6 thread-forming screws for plastics in
    printed pilot holes (~0.8 x diameter) instead of heat-set inserts, so
    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
    [6in-mirror-8in-tube-assembly.step, 6in-mirror-8in-tube-bom.csv, 6in-mirror-8in-tube-mirror-plate-print.step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]
2026-09-26 Add wear-washer locating marks at the push-bolt contacts
    - Ø1 × 1 mm marks on the mirror plate's rear face (bed side, no
    supports) under each push bolt, for cementing a steel flat washer as
    a wear pad (#6 SAE for #10-24, #10 SAE for 1/4-20)
    - Checks: washer seat on solid plastic incl. slide at full tilt and
    clear of the pull-insert hole; washer hole smaller than the bolt tip;
    tilted-pose clearance includes the washer thickness
    - Strength: push-bolt bearing now spread over the washer
    - BOM, hole schedule (M), drawing and assembly notes updated
    [6in-mirror-8in-tube-assembly.step, 6in-mirror-8in-tube-bom.csv, 6in-mirror-8in-tube-mirror-plate-print.step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]
2026-09-26 Fillet the mirror-plate arm roots in plane
    Each arm now meets the core through an 8 mm fillet tangent to the tapered
    arm edge and the core circle, removing the sharp re-entrant corners at the
    arm roots. Adds RULES.filletArm, a check that the fillet ends inboard of
    the lateral post, the fillets on the drawing, key dims, mass estimate and
    docs. Examples regenerated.
    [6in-mirror-8in-tube-assembly.step, 6in-mirror-8in-tube-bom.csv, 6in-mirror-8in-tube-mirror-plate-print.step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]
